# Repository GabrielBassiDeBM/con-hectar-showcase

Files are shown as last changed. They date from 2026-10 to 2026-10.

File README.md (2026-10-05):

<div align="center">

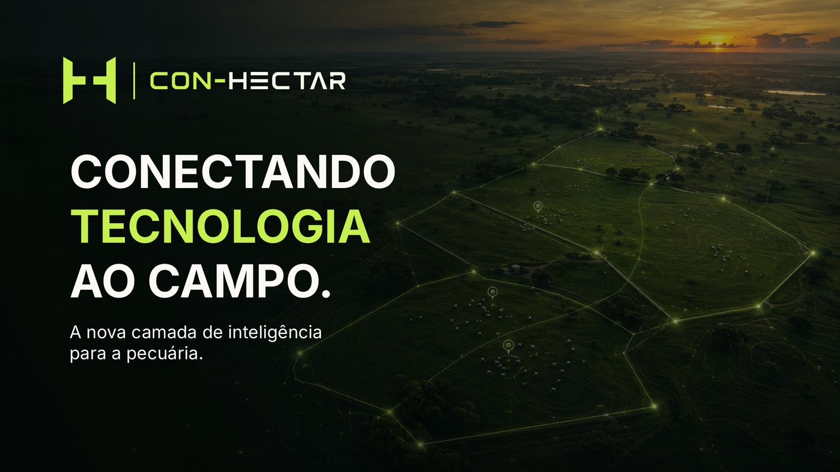
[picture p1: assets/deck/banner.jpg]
Con-Hectar — conectando tecnologia ao campo


<br/>
<br/>

<picture><source media="(prefers-color-scheme: dark)" srcset="assets/brand/logo-wordmark-tight-duotone.svg">Con-Hectar</picture>

### A nova camada de inteligência para a pecuária brasileira.

Coleiras GPS de baixo custo + rede LoRa própria + imagens de satélite Sentinel-2,<br/>
fundidas em um **sistema de decisão de pastejo**: quando tirar o lote, para onde mandar, e o que está errado agora.

<br/>

















[**Visão geral**](#-o-problema) ·
[**Como funciona**](#-como-funciona) ·
[**O que já foi construído**](#-o-que-já-foi-construído) ·
[**Hardware**](#-hardware) ·
[**Plataforma**](#-plataforma) ·
[**Inteligência**](#-a-inteligência) ·
[**Mercado**](#-mercado) ·
[**Roadmap**](#-desafios-e-próximos-passos)

</div>

---

> [!NOTE]
> **Este é um repositório de apresentação.** Ele documenta o que a Con-Hectar construiu — hardware, firmware, gateway, nuvem, painel web, app e motores de decisão — com fotos reais, arquitetura e números medidos em bancada. O código-fonte de produção é proprietário e fica em repositório privado; acesso para avaliação técnica pode ser concedido sob demanda.

<br/>

<p align="center">
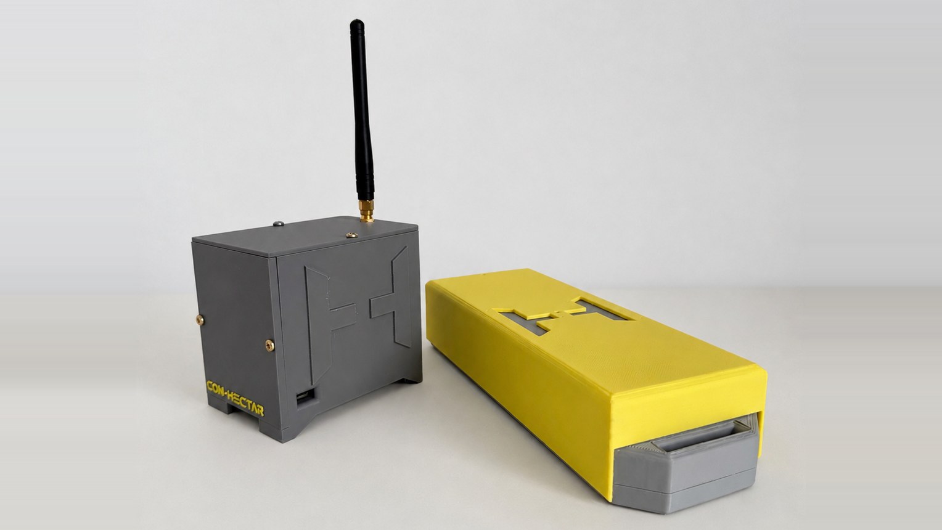
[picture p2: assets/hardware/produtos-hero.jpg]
Gateway (cinza) e coleira (amarela) da Con-Hectar
  
</p>
<p align="center"><sub><b>Hardware próprio.</b> O gateway (cinza) e a coleira (amarela) — eletrônica, firmware e cases projetados e impressos pela Con-Hectar.</sub></p>

<br/>

## ◆ O problema

<table>
<tr>
<td width="55%" valign="top">

A pecuária de corte brasileira é a maior do mundo em rebanho comercial — e uma das menos produtivas por hectare. A fazenda média produz **~5 @/ha/ano**; a fazenda bem manejada produz **12,9 @/ha/ano**. São **2,7×** de diferença na mesma terra, e **≈ R$ 441/ha/ano** de margem bruta deixada na porteira.

A maior parte desse gap não é genética nem insumo. É **manejo de pasto**: decidir *quando* tirar o lote de um piquete e *para onde* mandá-lo. Hoje isso é feito no "olhômetro", com uma ronda que, em fazenda extensiva, acontece a cada 3, 7 ou 15 dias.

Os produtos que já existem escolhem um lado: ou olham para o **animal** (rastreadores, brincos) ou olham para o **pasto** (satélite, NDVI). Nenhum funde os dois.

</td>
<td width="45%" valign="top">

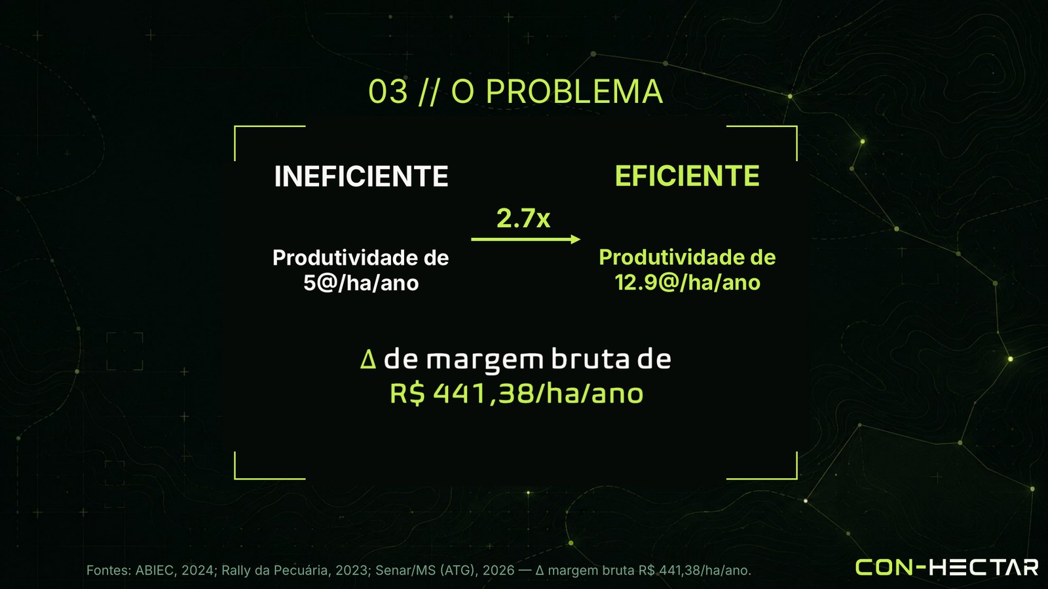
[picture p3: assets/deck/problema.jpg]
Ineficiente 5@/ha/ano vs eficiente 12,9@/ha/ano


<sub>Fontes: ABIEC, 2024; Rally da Pecuária, 2023; Senar/MS (ATG), 2026.</sub>

</td>
</tr>
</table>

### A tese

> **O rebanho avisa que o piquete acabou antes de o satélite conseguir enxergar isso.**
>
> Conforme a forragem se esgota, o bovino aumenta o tempo de pastejo e a distância percorrida de forma monotônica e mensurável. O satélite diz o que **tem** no piquete; o animal diz o que ele **acha** que tem. Quando os dois discordam, o animal ganha — porque ele está lá dentro. **Essa fusão é o produto.**

A Con-Hectar não vende rastreador. Vende um **sistema de suporte à decisão de pastejo cujo sensor primário é o próprio rebanho**, respondendo — sem que ninguém pergunte — às três perguntas que custam dinheiro na fazenda:

| | Pergunta | Hoje | Com a Con-Hectar |
|:-:|---|---|---|
| **1** | Quando tiro o lote deste piquete? | Olhômetro do capataz | Voto combinado **satélite × comportamento do rebanho** |
| **2** | Para onde mando? | Sequência fixa do croqui | Fila de rotação ranqueada pela forragem real e descanso aprendido |
| **3** | Tem algo errado com um animal ou com a infraestrutura? | Descoberto na próxima ronda | Alerta classificado, com evidência e ação sugerida |

<br/>

## ◆ Como funciona

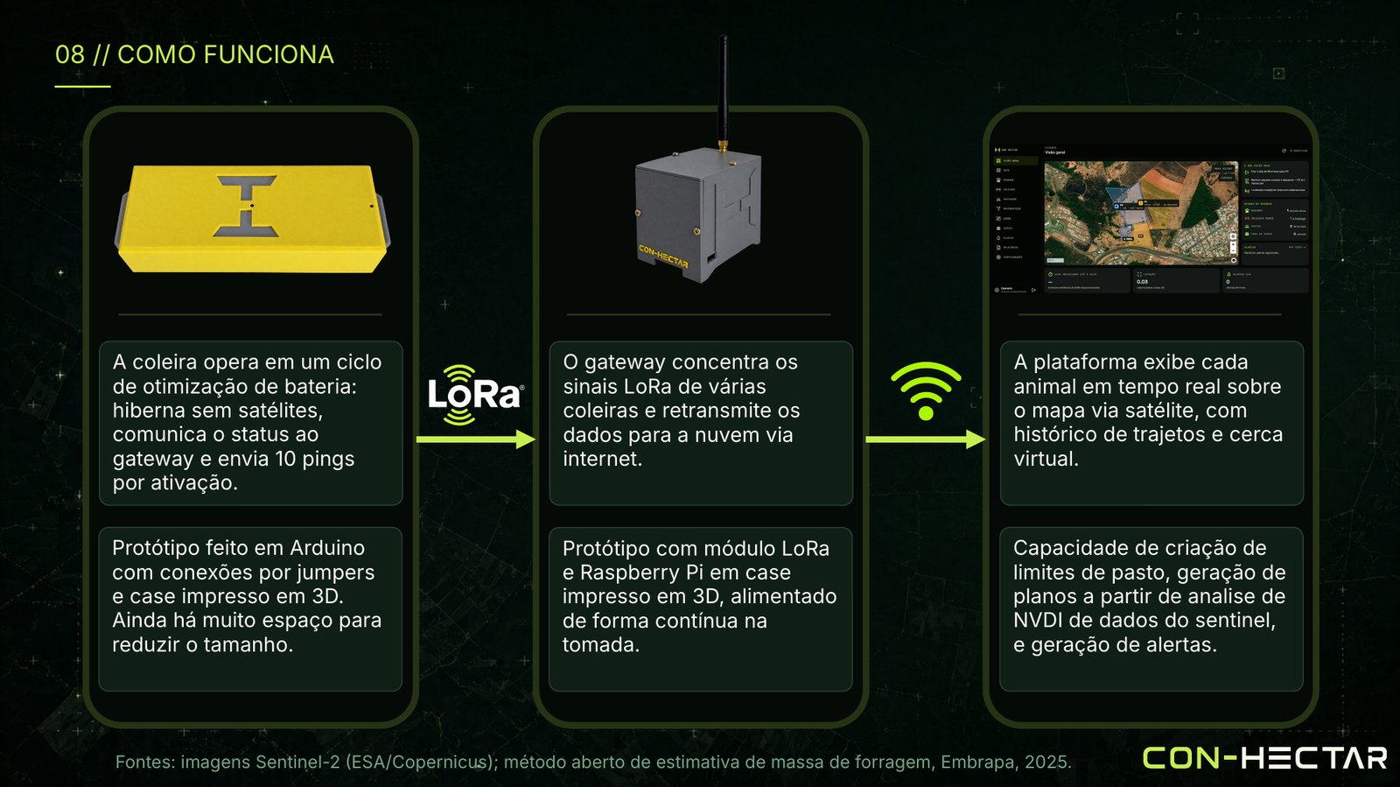
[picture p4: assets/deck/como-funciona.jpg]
Coleira → LoRa → Gateway → Nuvem → Plataforma


1. **Coleira** — acorda, obtém um fixo GPS, transmite por LoRa até receber confirmação do gateway e volta a dormir. Projetada para economizar bateria acima de tudo.
2. **Gateway** — concentra os sinais LoRa de várias coleiras, confirma o recebimento assim que o dado está **no próprio disco**, e encaminha para a nuvem sempre que houver internet. Continua operando quando a internet da fazenda cai.
3. **Nuvem** — cada fixo é imutável; métricas, rotação e alertas são derivados e recalculáveis. Imagens Sentinel-2 alimentam o NDVI de cada piquete automaticamente.
4. **Plataforma** — mapa em tempo real, cercas virtuais, plano de pastejo rotativo, saúde do rebanho e uma central de alertas que nunca confunde "animal parado" com "coleira sem sinal".

➜ Detalhes em [`docs/arquitetura.md`](docs/arquitetura.md)

<br/>

## ◆ O que já foi construído

Tudo abaixo existe, roda, e foi construído do zero — da solda ao pixel.

<table>
<tr>
<td width="50%" valign="top">

#### 🔧 Hardware & firmware
- [x] Coleira GPS + LoRa em Arduino, com case impresso em 3D
- [x] Firmware com ciclo de energia: GPS → transmite → aguarda ACK → dorme
- [x] Protocolo de rádio próprio com checksum, endereçamento e número de sequência
- [x] Anticolisão entre coleiras (jitter e backoff aleatórios por dispositivo)
- [x] Gerenciamento de energia do MCU e *sleep* do rádio por pinos de modo
- [x] Gateway em Raspberry Pi 5 com módulo LoRa, case 3D e serviço `systemd`
- [x] **Store-and-forward**: buffer local em SQLite que sobrevive a quedas de internet
- [x] Modelos 3D próprios da coleira e do gateway ([abrir no visualizador 3D](models/coleira.stl))

</td>
<td width="50%" valign="top">

#### ☁️ Nuvem & plataforma
- [x] Schema Postgres completo com Row Level Security
- [x] Stream de posições ao vivo via **Server-Sent Events**, autenticado
- [x] Painel web com **11 módulos** (mapa, rebanho, coleiras, cercas, pastagens, movimentação, saúde, alertas, relatórios…)
- [x] Desenho de cercas e piquetes direto no mapa de satélite
- [x] **Sincronização automática de NDVI** (Sentinel-2) por piquete
- [x] **Divisão automática de pastagens** em piquetes de área pastejável equivalente
- [x] **Motor de rotação**, **motor de anomalias** e **classificador de silêncio**
- [x] App de campo multiplataforma (iOS / Android / Web) em Expo
- [x] Landing page com visualizador 3D do hardware

</td>
</tr>
</table>

<br/>

## ◆ Hardware

Dois dispositivos, projetados do zero: a **coleira**, que vai no pescoço do animal, e o **gateway**, que fica na sede da fazenda.

<table>
<tr>
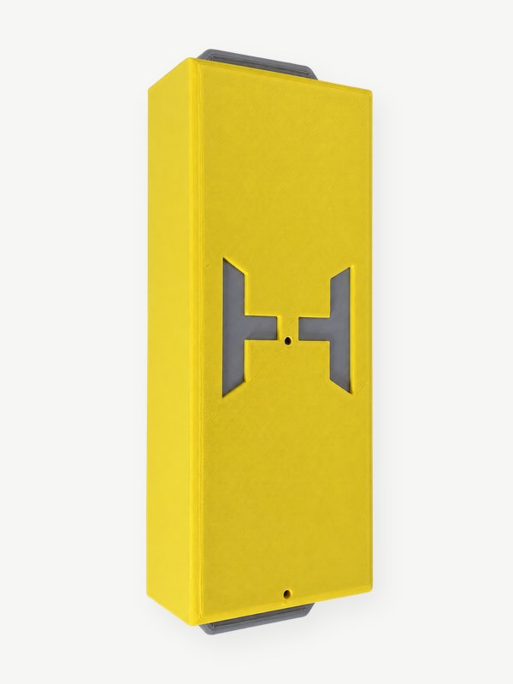
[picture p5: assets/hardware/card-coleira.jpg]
Coleira
<td align="center" width="25%"></td>
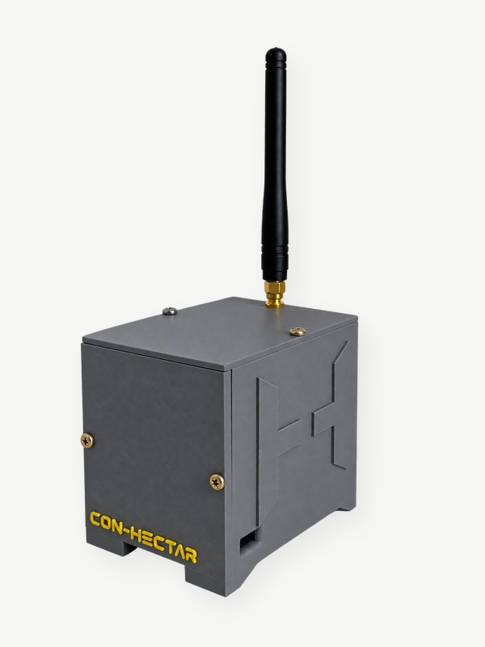
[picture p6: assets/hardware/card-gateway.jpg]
Gateway
<td align="center" width="25%"></td>
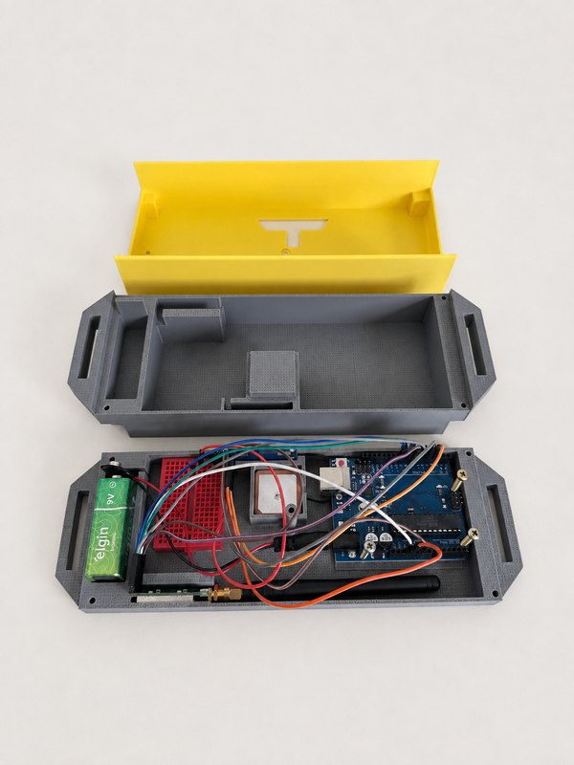
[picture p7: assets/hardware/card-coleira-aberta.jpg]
Coleira aberta mostrando a eletrônica
<td align="center" width="25%"></td>
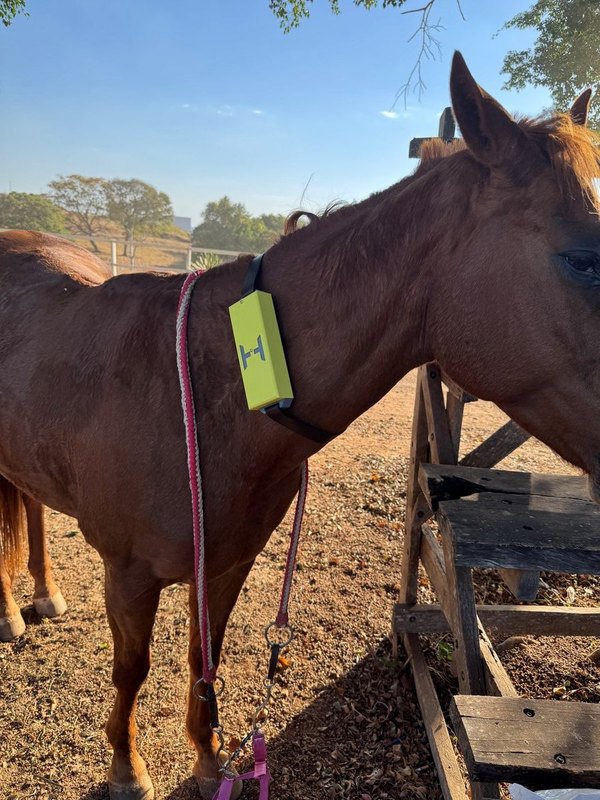
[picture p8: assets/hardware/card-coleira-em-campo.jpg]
Coleira instalada em um animal
<td align="center" width="25%"></td>
</tr>
<tr>
<td align="center" valign="top"><sub><b>Coleira</b><br/>GNSS + LoRa, a bateria</sub></td>
<td align="center" valign="top"><sub><b>Gateway</b><br/>Raspberry Pi 5 + LoRa, na sede</sub></td>
<td align="center" valign="top"><sub><b>Por dentro da coleira</b><br/>MCU, GNSS, rádio e bateria</sub></td>
<td align="center" valign="top"><sub><b>Teste em animal</b><br/>Fixação no pescoço</sub></td>
</tr>
</table>

#### Da folha de caderno ao campo

<table>
<tr>
<th width="25%">① Esquemático</th>
<th width="25%">② Coleira na bancada</th>
<th width="25%">③ Gateway na bancada</th>
<th width="25%">④ Case final</th>
</tr>
<tr>
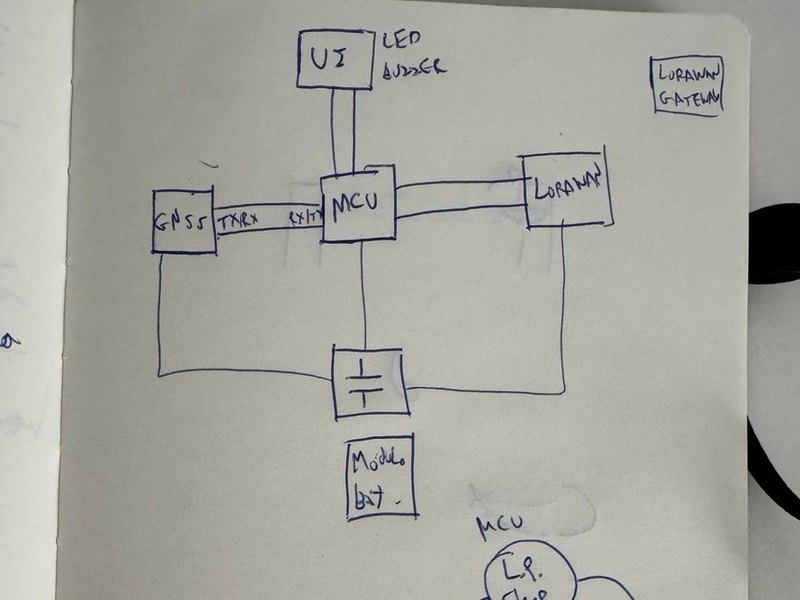
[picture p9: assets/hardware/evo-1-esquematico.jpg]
Esquemático à mão
<td></td>
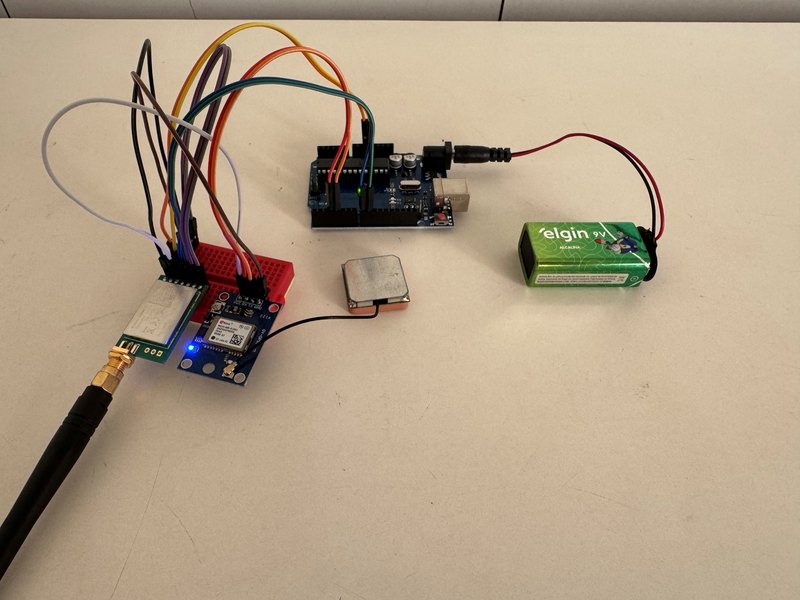
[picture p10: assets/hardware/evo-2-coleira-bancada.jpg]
Coleira em protoboard
<td></td>
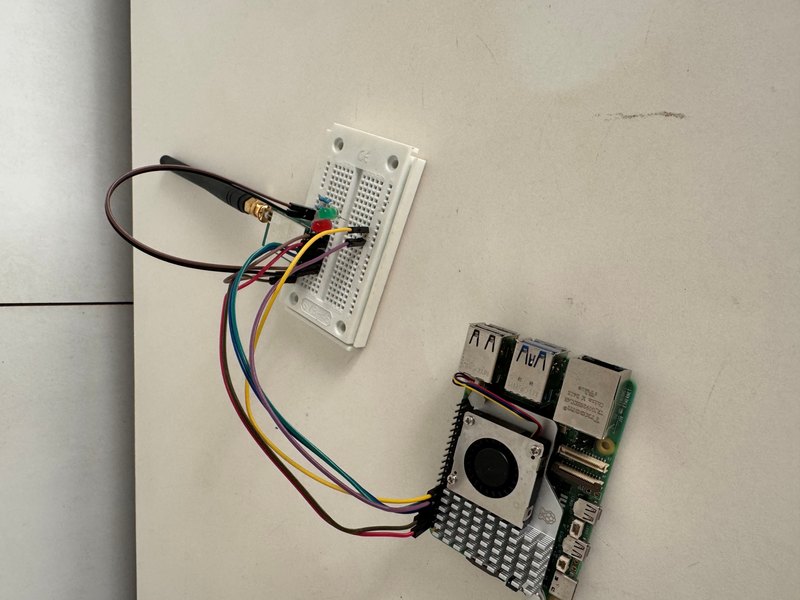
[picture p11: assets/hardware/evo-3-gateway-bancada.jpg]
Gateway em protoboard
<td></td>
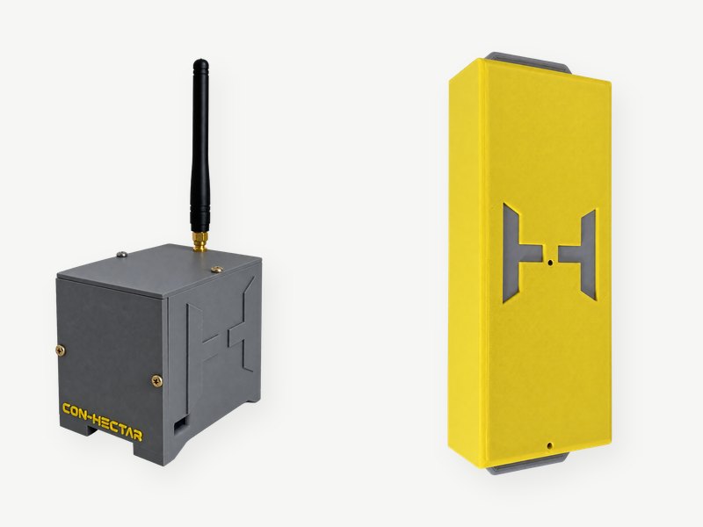
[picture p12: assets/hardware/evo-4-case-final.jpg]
Cases finais
<td></td>
</tr>
<tr>
<td align="center" valign="top"><sub>Arquitetura e ciclo de sono rascunhados à mão</sub></td>
<td align="center" valign="top"><sub>MCU + GNSS + LoRa em jumpers</sub></td>
<td align="center" valign="top"><sub>Raspberry Pi 5 + LoRa via UART</sub></td>
<td align="center" valign="top"><sub>Cases projetados e impressos em 3D</sub></td>
</tr>
</table>

#### Modelos 3D

Os cases foram modelados do zero — são os mesmos modelos do visualizador 3D da landing page. Clique em uma imagem para abrir o modelo no visualizador interativo do GitHub e **girar, aproximar e inspecionar**.

<table>
<tr>
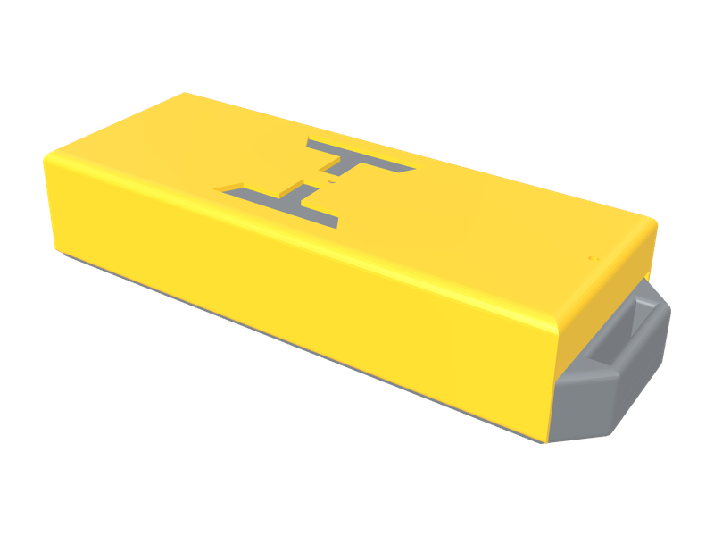
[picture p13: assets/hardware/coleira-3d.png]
Modelo 3D da coleira
<td align="center" width="50%"></td>
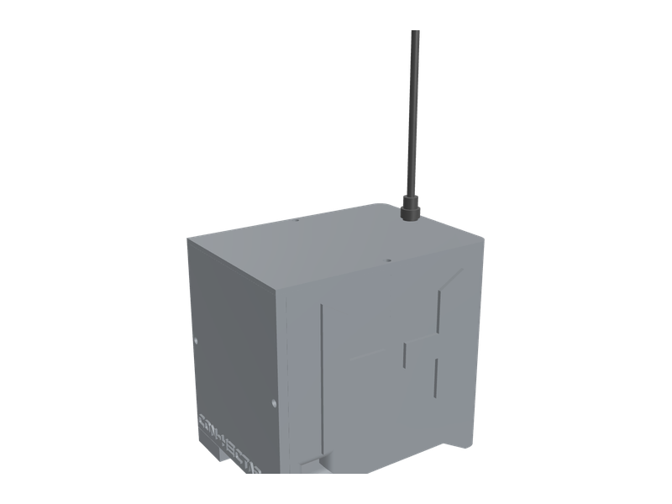
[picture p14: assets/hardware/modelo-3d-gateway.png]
Modelo 3D do gateway
<td align="center" width="50%"></td>
</tr>
<tr>
<td align="center"><a href="models/coleira.stl"><b>Coleira</b></a> · <code>models/coleira.stl</code></td>
<td align="center"><a href="models/gateway.stl"><b>Gateway</b></a> · <code>models/gateway.stl</code></td>
</tr>
</table>

#### Especificações

| Componente | Coleira | Gateway |
|---|---|---|
| **Processamento** | Microcontrolador AVR (protótipo) → MCU de baixo consumo (próxima rev.) | Raspberry Pi 5 · Debian 13 |
| **Posicionamento** | GNSS u-blox | — |
| **Rádio** | LoRa sub-GHz, faixa ISM ANATEL | LoRa sub-GHz, mesma faixa |
| **Software** | Firmware C++ com máquina de estados de energia | Serviço Python: ACK · armazenar · encaminhar · podar |
| **Persistência** | — | SQLite local (sobrevive a quedas de internet) |
| **Alimentação** | Bateria | Contínua (tomada) |
| **Case** | Impresso em 3D, projeto próprio | Impresso em 3D, projeto próprio |

➜ Detalhes em [`docs/hardware.md`](docs/hardware.md)

<br/>

## ◆ Plataforma

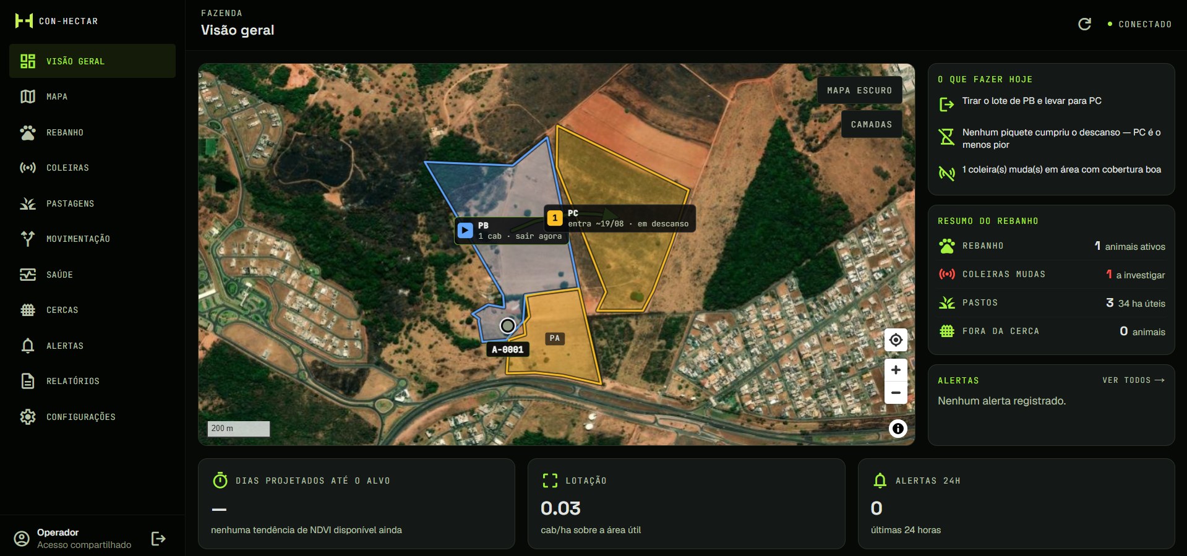
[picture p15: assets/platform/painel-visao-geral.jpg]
Painel Con-Hectar — visão geral


<sub>Painel em funcionamento: mapa de satélite com piquetes, lotes e coleiras ao vivo; à direita, "o que fazer hoje" e o resumo do rebanho.</sub>

<table>
<tr>
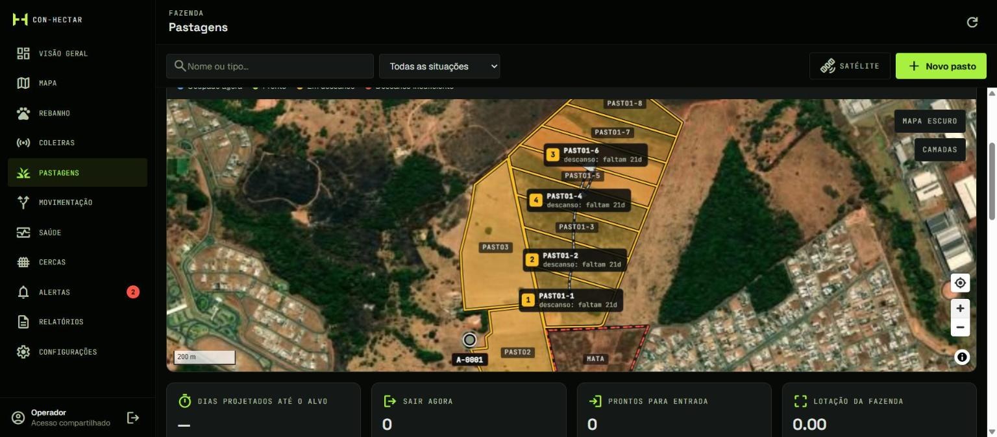
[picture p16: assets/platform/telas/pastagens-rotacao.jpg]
Pastagens — mapa da rotação
<td width="50%"></td>
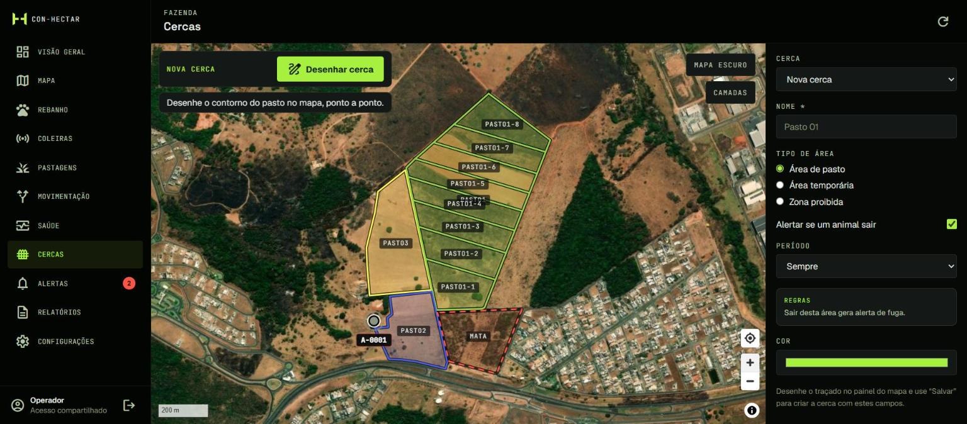
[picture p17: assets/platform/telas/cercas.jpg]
Cercas virtuais
<td width="50%"></td>
</tr>
<tr>
<td valign="top"><sub><b>Pastagens</b> — pastagem dividida automaticamente em 8 piquetes, com a fila de rotação numerada e o tempo de descanso restante de cada um.</sub></td>
<td valign="top"><sub><b>Cercas</b> — piquetes, área de mata como zona proibida e a coleira C0001 sobre imagem de satélite.</sub></td>
</tr>
<tr>
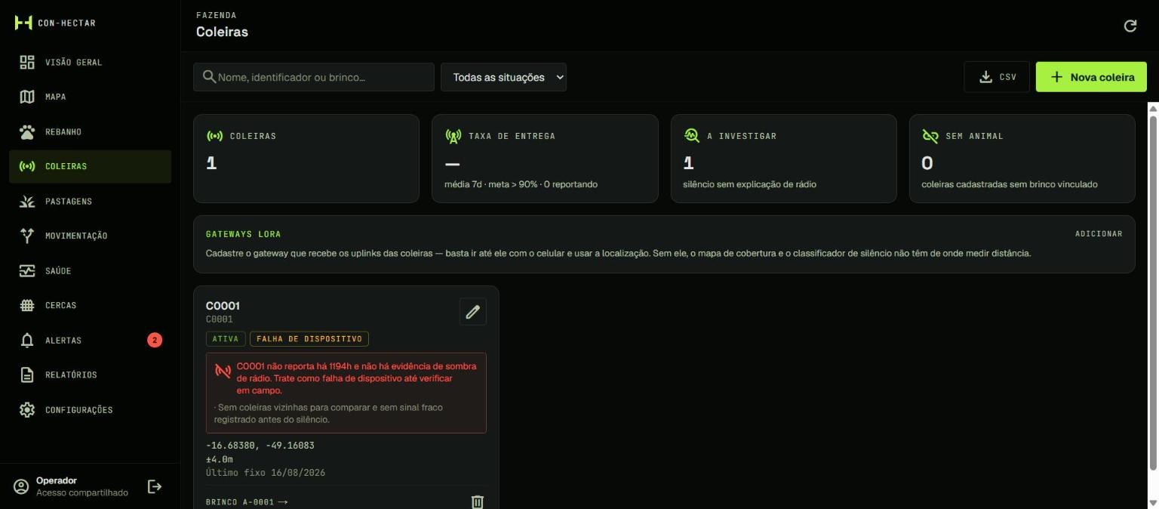
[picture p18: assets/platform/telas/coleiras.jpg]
Coleiras — diagnóstico de silêncio
<td width="50%"></td>
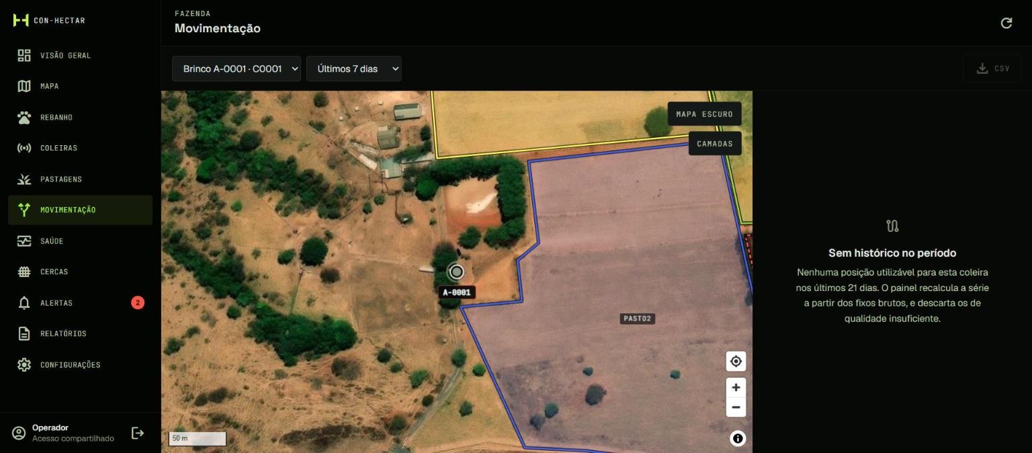
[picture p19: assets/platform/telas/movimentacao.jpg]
Movimentação
<td width="50%"></td>
</tr>
<tr>
<td valign="top"><sub><b>Coleiras</b> — o classificador de silêncio em ação: sem sombra de rádio que explique, a coleira é marcada como falha de dispositivo.</sub></td>
<td valign="top"><sub><b>Movimentação</b> — trajeto por animal e período; dias sem fixos de qualidade são recusados em vez de inventados.</sub></td>
</tr>
</table>

| Módulo | O que resolve |
|---|---|
| **Visão geral** | O que fazer hoje — recomendações priorizadas, não um mural de gráficos |
| **Mapa** | Cada animal em tempo real sobre imagem de satélite, com trajetos, gateways e pontos de recurso (cocho, água) |
| **Rebanho** | Cadastro de animais e lotes, vínculo animal ↔ coleira com histórico temporal |
| **Coleiras** | Estado de cada dispositivo, qualidade de rádio e diagnóstico de silêncio |
| **Cercas** | Cercas virtuais com regras de entrada/saída por período, detecção de fuga com histerese |
| **Pastagens** | Piquetes, NDVI, estado (ocupado · pronto · descansando), fila de rotação e divisão automática |
| **Movimentação** | Distância, área de uso e orçamento de atividade por animal e por lote |
| **Saúde** | Eventos sanitários e anomalias comportamentais com evidência |
| **Alertas** | Central de alertas com severidade, explicação e ação sugerida |
| **Relatórios** | Indicadores históricos para decisão e prestação de contas |
| **Configurações** | Fazenda, intervalos de amostragem, limiares |

➜ Detalhes em [`docs/plataforma.md`](docs/plataforma.md)

<br/>

## ◆ A inteligência

A plataforma é organizada em **cinco camadas**, cada uma alimentando a seguinte. Todas são derivadas **apenas de posição, tempo e satélite** — sem prometer o que o hardware não mede.

```mermaid
flowchart LR
  L0["<b>0 · Dados</b><br/>fixos imutáveis"]
  L1["<b>1 · Comportamento</b><br/>~20 métricas<br/>por animal-dia"]
  L2["<b>2 · Piquete</b><br/>ciclo de ocupação"]
  L3["<b>3 · Satélite</b><br/>NDVI Sentinel-2"]
  L4["<b>4 · Rotação</b><br/>sair? para onde?"]
  L5["<b>5 · Alertas</b><br/>anomalias · silêncio"]
  L0 --> L1 --> L2 --> L4
  L3 --> L4
  L1 --> L5
  L4 --> L5
```

| Motor | O que faz | Por que é diferente |
|---|---|---|
| **Métricas comportamentais** | Distância filtrada, sinuosidade, área de uso, raio de giro, tempo em pastejo × deslocamento × repouso | Filtra a "caminhada fantasma" do erro de GPS e se recusa a comparar dias com intervalos de amostragem diferentes |
| **Rotação** | Decide quando sair do piquete por **voto de duas fontes** — satélite e comportamento — e ranqueia o próximo | Quando as fontes discordam, a interface **mostra a discordância** em vez de esconder |
| **Satélite (NDVI)** | Sincroniza Sentinel-2 por piquete e aprende os limiares de entrada/saída **do próprio histórico do piquete** | Zero calibração manual: nenhum operador escolhe espécie ou digita altura de capim |
| **Anomalias** | Falha de aguada, animal caído, doença, isolamento, coesão do rebanho, cio | Linha de base robusta (mediana/MAD), normalizada contra o próprio lote no mesmo dia, com persistência — e dez animais com a mesma anomalia viram **um** alerta de infraestrutura |
| **Silêncio** | Classifica por que uma coleira parou de falar: sombra de rádio, falha de dispositivo ou silêncio sem explicação | Um falso "animal morto" queima mais confiança do que dez acertos constroem |
| **Divisão de pastagens** | Corta uma pastagem em N piquetes de área pastejável equivalente, como um cerqueiro faria | Balanceada por NDVI; sugere N a partir de dias de descanso e ocupação |

➜ Detalhes em [`docs/inteligencia.md`](docs/inteligencia.md)

<br/>

## ◆ Medido, não estimado

Uma regra da casa: **o que foi medido é marcado como medido; o que foi calculado é marcado como calculado.**

| Verificação | Resultado | Tipo |
|---|:-:|---|
| Link GPS (sentenças NMEA com checksum válido) | **120 / 0** | ✅ medido |
| Frames de rádio coleira → gateway | **6 / 0 perdidos** | ✅ medido |
| Latência de ingestão (fixo armazenado → nuvem) | **7 s** | ✅ medido |
| Stream ao vivo sem / com sessão | **401 / 200** | ✅ medido |
| Ganho do sono do MCU no consumo médio | ≈ 2 % | ⚠️ calculado — revelou que o gargalo é o GNSS e a placa, não o MCU |

➜ Diário completo, incluindo as falhas encontradas, em [`docs/engenharia.md`](docs/engenharia.md)

<br/>

## ◆ Mercado

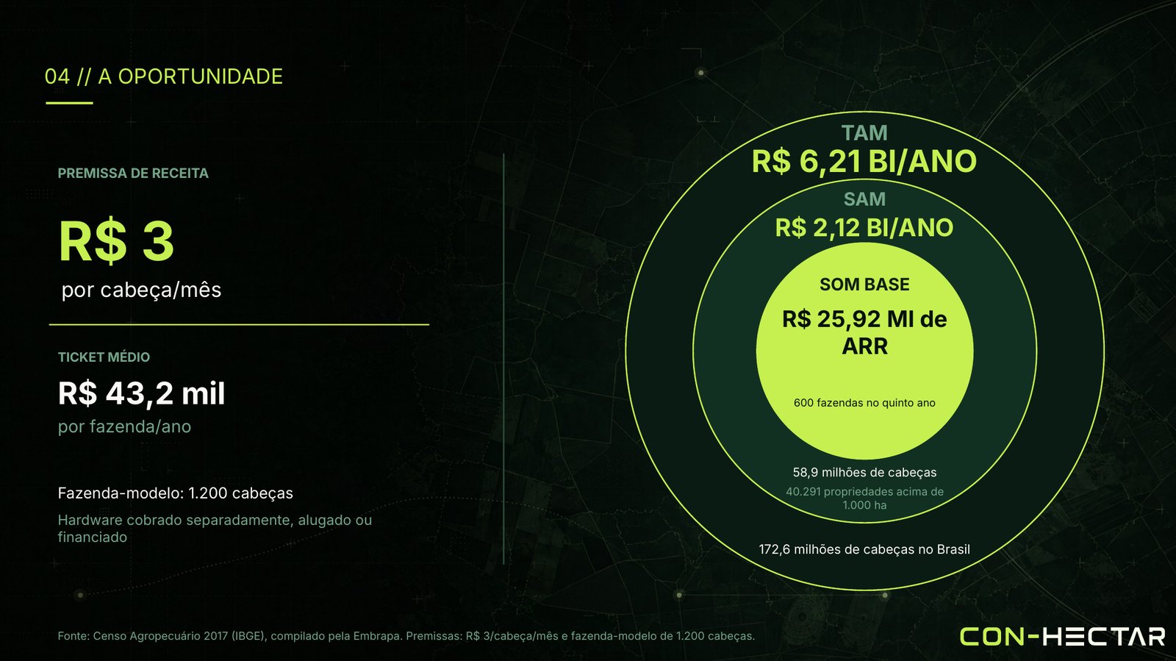
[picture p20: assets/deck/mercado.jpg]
TAM, SAM e SOM


<p align="center">
🐂 <b>238 mi</b> cabeças de gado &nbsp;·&nbsp; 🌱 <b>167 mi ha</b> de pastagem &nbsp;·&nbsp; 💰 <b>R$ 1,1 tri</b> movimentados por ano
</p>

**Modelo:** assinatura de **R$ 3 por cabeça/mês** (ticket médio de R$ 43,2 mil/fazenda/ano numa fazenda-modelo de 1.200 cabeças). Hardware cobrado à parte — venda, aluguel ou financiamento. Cobrar por cabeça, e não por coleira, só se justifica porque o produto entrega **decisão**, não posição.

➜ Detalhes em [`docs/negocio.md`](docs/negocio.md)

<br/>

## ◆ Desafios e próximos passos

<table>
<tr>
<td width="50%" valign="top">

#### Desafios honestos
- Conexão do gateway à internet instável no último teste de campo, feito sem Starlink
- Jumpers e módulos de prateleira elevaram custo e tamanho da coleira
- Imagens de satélite escassas em períodos de seca geraram erros nos piquetes
- O sono do MCU rende pouco: o consumo está no GNSS e na placa de desenvolvimento

</td>
<td width="50%" valign="top">

#### Próximos passos
- [ ] Estabilizar o link do gateway em campo
- [ ] **Cyberdeck**: gateway com sistema operacional e tela próprios, para monitorar o rebanho na fazenda sem depender de rede
- [ ] Melhorar a geração automática de piquetes
- [ ] Coleira em **PCB própria** com MCU de baixo consumo
- [ ] Modo *power-save* do GNSS e buffer de fixos na coleira
- [ ] Piloto com **+1 coleira ativa** e depois um lote inteiro

</td>
</tr>
</table>

➜ Roadmap completo em [`docs/negocio.md#roadmap`](docs/negocio.md#roadmap)

<br/>

## ◆ Linha do tempo

| Fase | Marco | Entregas |
|:-:|---|---|
| **01** | Entender o problema | Pesquisa e conversas com pecuaristas · esquemático da eletrônica · consolidação da tese |
| **02** | Provar a cadeia | Eletrônica em bancada · fazenda-piloto definida · documento de requisitos de produto · planejamento do software |
| **03** · *atual* | Construir o produto | **15/08** coleira C0001 → gateway → nuvem → mapa ao vivo, ponta a ponta · **19/08** motor de rotação, sync NDVI Sentinel-2, divisão automática de piquetes e motor de alertas · cases 3D, modelos 3D e teste de fixação em animal |

<br/>

## ◆ Documentação

| Documento | Conteúdo |
|---|---|
| [`docs/arquitetura.md`](docs/arquitetura.md) | Cadeia ponta a ponta, protocolo de rádio, modelo de dados, decisões de projeto, segurança |
| [`docs/hardware.md`](docs/hardware.md) | Coleira, gateway, ciclo de energia, análise de consumo, evolução do protótipo |
| [`docs/plataforma.md`](docs/plataforma.md) | Painel web, app de campo, sistema de design e princípios de produto |
| [`docs/inteligencia.md`](docs/inteligencia.md) | As cinco camadas: métricas, satélite, rotação, anomalias e silêncio |
| [`docs/engenharia.md`](docs/engenharia.md) | O que foi medido, falhas encontradas e como foram resolvidas, itens em aberto |
| [`docs/negocio.md`](docs/negocio.md) | Problema, mercado, concorrência, modelo de receita e roadmap |

<br/>

---

<div align="center">



**Con-Hectar** · Goiânia, GO

Fundador: **Gabriel Bassi** — [gabrielbassidebm@gmail.com](mailto:gabrielbassidebm@gmail.com)

<sub>© 2026 Con-Hectar. Todos os direitos reservados. Fotos, renders, marcas e documentação deste repositório não podem ser reproduzidos sem autorização.</sub>

</div>

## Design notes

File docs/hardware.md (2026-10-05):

<picture><source media="(prefers-color-scheme: dark)" srcset="../assets/brand/logo-wordmark-tight-duotone.svg">Con-Hectar</picture>

# Hardware

[← Voltar ao README](../README.md)

Gateway (cinza) e coleira (amarela)

Dois dispositivos, ambos projetados, montados, programados e encapsulados pela Con-Hectar: a **coleira** (amarela), que vai no animal, e o **gateway** (cinza), que fica na sede da fazenda.

---

## Coleira

<table>
<tr>
<td width="30%" align="center" valign="top">Coleira</td>
<td valign="top">

**Função:** acordar, obter um fixo GNSS, entregá-lo ao gateway com confirmação e voltar a dormir — gastando o mínimo de energia possível.

**Protótipo atual**
- Microcontrolador AVR em placa de desenvolvimento
- Receptor GNSS u-blox
- Transceptor LoRa sub-GHz em modo transparente
- Bateria e chave de alimentação
- Case impresso em 3D, com encaixe para correia

**Firmware** em C++, organizado como uma máquina de estados de energia. A coleira opera em um ciclo de otimização de bateria: hiberna sem satélites, comunica o status ao gateway e envia uma rajada de pings por ativação.

</td>
</tr>
</table>

### O ciclo de trabalho

```
acorda
 ├─ escuta o GNSS até obter um fixo NOVO (ou estourar o tempo)
 ├─ monta o frame: $P (fixo) ou $S (sem fixo)
 ├─ troca a escuta para o rádio
 ├─ atraso aleatório
 ├─ até N tentativas:  transmite → aguarda ACK → backoff aleatório
 ├─ seq++
 └─ dorme: rádio em modo sleep, MCU em power-down
```

Três armadilhas resolvidas de forma deliberada no firmware:

- **O relógio do MCU congela no power-down**, então a "idade" do fixo não distingue um fixo novo do anterior. A coleira espera o contador de fixos do GNSS avançar.
- **As portas seriais em software ficam em interrupções de mudança de pino.** São desligadas explicitamente antes de dormir — caso contrário, o próximo caractere do GNSS acordaria o MCU na hora e o sono nunca aconteceria.
- **A libc do AVR não formata ponto flutuante.** Coordenadas passam por conversão dedicada; sem isso, latitude e longitude seriam transmitidas vazias.

### Energia — a análise que mudou o roadmap

Implementamos o sono profundo do MCU, o desligamento de periféricos internos e o sono do rádio via pinos de modo. Depois, fizemos a conta honesta:

| Carga | Antes | Depois | Alcançável por firmware? |
|---|---:|---:|---|
| Receptor GNSS | alta | alta | Só com comandos UBX — exige um fio a mais |
| Rádio LoRa | média | ≈ 0 | **Sim** — agora dorme |
| Placa de desenvolvimento (USB, LED, regulador) | média | média | Não — é da placa |
| Microcontrolador | baixa | piso | **Sim** — já no mínimo |
| **Média do ciclo** | | | **≈ 2 % melhor** *(calculado, não medido)* |

**Conclusão:** o MCU é a menor carga do sistema por três ordens de grandeza. O ganho real está em (1) colocar o GNSS em modo de economia, (2) mudar a razão acordado/dormindo e (3) **sair da placa de desenvolvimento para uma PCB própria com MCU de baixo consumo** — exatamente o que está no roadmap. Essa análise evitou que dimensionássemos uma bateria com base numa otimização que não existia.

---

## Gateway

<table>
<tr>
<td width="30%" align="center" valign="top">Gateway</td>
<td valign="top">

**Função:** concentrar os sinais LoRa de várias coleiras e retransmitir os dados para a nuvem via internet.

- Raspberry Pi 5, Debian 13
- Módulo LoRa ligado por UART
- Antena externa
- Case impresso em 3D
- Alimentação contínua (tomada)

**Software:** serviço Python gerenciado por `systemd`, que reinicia sozinho e sobe no boot. Quatro responsabilidades:

1. **Confirmar** cada frame válido com o ACK endereçado
2. **Armazenar** em SQLite local, antes de qualquer outra coisa
3. **Encaminhar** para a nuvem quando houver internet
4. **Podar** o buffer com um teto de retenção

Inclui ainda um script de preparação que libera a UART em um Pi recém-instalado e um monitor passivo para trabalho de bancada.

</td>
</tr>
</table>

---

## Evolução do protótipo

<table>
<tr>
<th width="25%">Fase 01 · Esquemático</th>
<th width="25%">Fase 02 · Coleira</th>
<th width="25%">Fase 02 · Gateway</th>
<th width="25%">Fase 03 · Case</th>
</tr>
<tr>
<td>Esquemático</td>
<td>Coleira em bancada</td>
<td>Gateway em bancada</td>
<td>Cases finais</td>
</tr>
<tr>
<td valign="top"><sub>Blocos, barramentos e ciclo de sono desenhados à mão — já apontando para um MCU de baixo consumo e chave eletrônica na alimentação</sub></td>
<td valign="top"><sub>MCU + GNSS + LoRa + bateria em jumpers</sub></td>
<td valign="top"><sub>Raspberry Pi 5 + LoRa em protoboard</sub></td>
<td valign="top"><sub>Coleira e gateway nos cases impressos em 3D</sub></td>
</tr>
</table>

### Em animal

<table>
<tr>
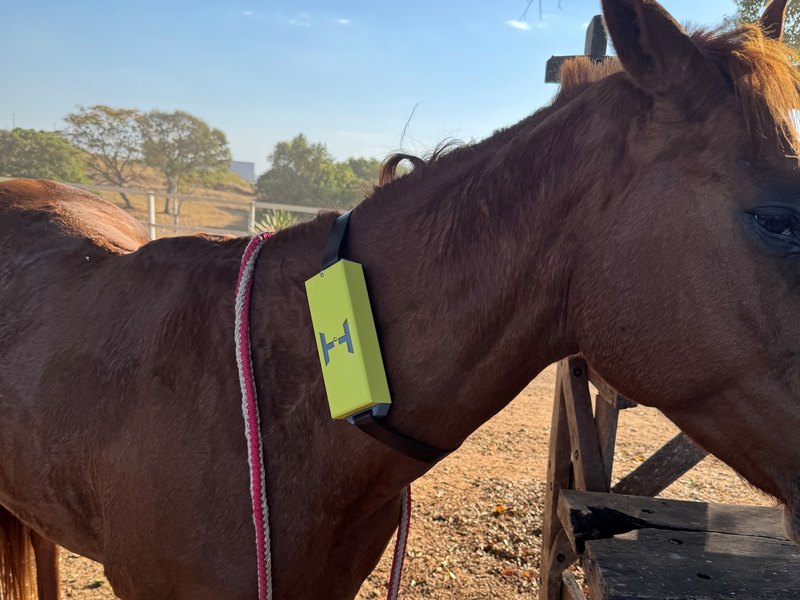
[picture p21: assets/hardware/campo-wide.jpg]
Coleira em animal
<td width="50%" align="center"></td>
<td valign="top">

Teste de fixação da coleira, já no case final, no pescoço de um animal.

O teste valida o encaixe da correia e o posicionamento do case. Os próximos passos de campo estão no fim desta página: PCB própria e uma segunda coleira ativa.

</td>
</tr>
</table>

### Modelos 3D

Os cases foram modelados do zero. Clique para abrir no visualizador 3D interativo do GitHub — os mesmos modelos aparecem na landing page, renderizados com Three.js.

<table>
<tr>
<td align="center" width="50%"><a href="../models/coleira.stl">Modelo 3D da coleira</a></td>
<td align="center" width="50%"><a href="../models/gateway.stl">Modelo 3D do gateway</a></td>
</tr>
<tr>
<td align="center"><a href="../models/coleira.stl"><b>Coleira</b></a> · <code>models/coleira.stl</code></td>
<td align="center"><a href="../models/gateway.stl"><b>Gateway</b></a> · <code>models/gateway.stl</code></td>
</tr>
</table>

---

## Próxima revisão

| Item | Por quê |
|---|---|
| **PCB própria** | Elimina jumpers e a placa de desenvolvimento: menor custo, menor tamanho, menor consumo de base |
| **MCU de baixo consumo** | Sono real em microamperes |
| **GNSS em modo power-save** | Atua sobre 100 % do tempo, não sobre a fração em que a coleira dorme |
| **Buffer de fixos na coleira** | Hoje, se a coleira não alcança o gateway, o fixo do ciclo é descartado. Com buffer, ela descarrega o histórico ao voltar à cobertura ("modo mochila") |
| **Medição de bateria** | Só será mostrada no painel quando for medida de verdade |
| **Segunda coleira ativa** | Validar anticolisão e endereçamento em campo |
| **Gateway como cyberdeck** | O link de internet ficou instável no último teste (sem Starlink). Com sistema operacional e tela próprios, o gateway passa a mostrar o rebanho direto na sede, sem depender de rede — a nuvem vira sincronização, não requisito |

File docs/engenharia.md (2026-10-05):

<picture><source media="(prefers-color-scheme: dark)" srcset="../assets/brand/logo-wordmark-tight-duotone.svg">Con-Hectar</picture>

# Diário de engenharia

[← Voltar ao README](../README.md)

Extraído do relatório de sistema da coleira **C0001**: o que foi medido no sistema rodando, as falhas encontradas — cada uma se apresentando como algo diferente do que era — e o que continua em aberto.

---

## O que foi medido

Do sistema em funcionamento, não de raciocínio sobre ele.

| Verificação | Resultado | Por que essa é a verificação certa |
|---|:-:|---|
| Link GPS | **120 / 0** sentenças com checksum válido / inválido | A contagem de caracteres sobe mesmo lendo ruído no baud errado; só checksums válidos provam o link |
| Frames de rádio | **6 / 0 perdidos** | O gateway decodificou byte a byte o que a coleira imprimiu, confirmado por contadores nas duas pontas |
| Latência de ingestão | **7 s** | Fixo gravado às 03:30:48, enviado às 03:30:55 |
| Gatilho de retenção | **6 → 3** | Verificado com um teto reduzido num dispositivo descartável; dados reais intocados, teto restaurado |
| Autenticação do stream | **401 / 200** | Recusado sem cookie de sessão, servido com ele |

```
03:30:48  C0001 seq=26 -16.71…,-49.26… @ 03:30:47  (stored)
03:30:48    ack -> $A,C0001,26*07
03:30:55  uploaded 1
```

> ⚠️ **Consumo de energia: calculado, não medido.** Valores típicos de datasheet; nenhum multímetro esteve no sistema ainda. Ver [`hardware.md`](hardware.md#energia--a-análise-que-mudou-o-roadmap).

---

## Falhas encontradas

| Sintoma | O que realmente era | Correção |
|---|---|---|
| **O mapa abria na cidade errada** | Sem cercas nem centro da fazenda configurados, o mapa caía num padrão nacional enquanto a única coleira estava a ~200 km. Ela estava sendo desenhada o tempo todo — fora da tela. | Enquadramento automático nas coleiras ativas |
| **Frames corrompidos que não eram problema de rádio** | Caracteres faltando, mas os sobreviventes *em ordem* — dois processos lendo a mesma UART e roubando bytes um do outro. | Um único dono da porta serial |
| **Um comando funcionando que parecia morto** | Python bufferiza stdout num pipe; um monitor rodando via SSH não imprimia nada por minutos. Esse silêncio deixou o processo duplicado acima vivo. | Saída sem buffer |
| **Todo ciclo transmitindo duas vezes** | A tentativa 1 sempre expirava e a 2 sempre era confirmada. Pacote perdido é aleatório; "a primeira sempre falha" é uma resposta chegando depois da janela. Um teste A/B descartou o sono do rádio como causa. | Janela de ACK dobrada |
| **Um sentinela fingindo ser dado** | HDOP 99,99 ("sem precisão") chegava ao banco como precisão de ~500 m — um círculo que o mapa desenharia feliz. | Sentinelas filtrados na origem |
| **Um feed ao vivo sem autenticação** | O stream de posições ficava fora do código de acesso que protegia o painel acima dele. | Stream exige sessão |
| **Uma função interna exposta publicamente** | A API REST publica tudo no schema público; a função de retenção era chamável de fora. | Movida para fora do schema exposto |

---

## Decisões de produto tiradas da engenharia

- **O painel deixou de mostrar bateria.** Não há divisor nem leitura de ADC na coleira, então qualquer número seria inventado. Removemos toda superfície de bateria em vez de exibir um dado que teríamos de adivinhar.
- **O ACK não espera a nuvem** (ver [`arquitetura.md`](arquitetura.md#3-a-decisão-mais-importante-o-ack-não-espera-a-nuvem)).
- **A análise de energia redirecionou o roadmap** do firmware para a PCB.

---

## Em aberto

| Item | Tipo | Situação |
|---|---|---|
| Proteção de nível lógico entre MCU e rádio | Hardware | Mitigado em firmware em parte dos pinos; divisores resistivos pendentes |
| Coleira não guarda fixos quando não alcança o gateway | Perda de dados | Buffer em memória não volátil planejado ("modo mochila") |
| Conectividade do gateway | Implantação | Instável no último teste de campo, feito sem Starlink. Caminhos: um link de internet estável na sede, ou um **cyberdeck** — o gateway com sistema operacional e tela próprios, exibindo o rebanho localmente sem precisar de rede |
| Alertas de cerca derivados no navegador | Arquitetura | Funciona com o painel aberto; migrar a derivação para o gateway, que já vê todo fixo |
| Leitura de bateria | Funcionalidade | Depende da nova PCB |
| Validação da integração Sentinel-2 com conta de produção | Integração | Pendente de credenciais definitivas |

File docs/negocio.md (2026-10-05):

<picture><source media="(prefers-color-scheme: dark)" srcset="../assets/brand/logo-wordmark-tight-duotone.svg">Con-Hectar</picture>

# Negócio

[← Voltar ao README](../README.md)

> **Nossa direção:** a melhor versão do campo na palma da mão de quem mais precisa.

---

## O problema

Produtividade: 5 vs 12,9 @/ha/ano

| | Produtividade | |
|---|:-:|---|
| Fazenda ineficiente | **5 @/ha/ano** | |
| Fazenda eficiente | **12,9 @/ha/ano** | **2,7×** |
| Diferença de margem bruta | **R$ 441,38/ha/ano** | |

<sub>Fontes: ABIEC, 2024; Rally da Pecuária, 2023; Senar/MS (ATG), 2026.</sub>

O gap é, em grande parte, de **manejo de pastagem** — decidido hoje no olho, com rondas espaçadas e sem dado.

---

## O mercado

| Indicador | Valor | Fonte |
|---|:-:|---|
| Rebanho bovino | **238 mi** cabeças | IBGE, PPM 2024 |
| Movimentado pela cadeia | **R$ 1,1 tri/ano** | ABIEC, Beef Report 2026 |
| Área de pastagem | **167 mi ha** | ABIEC, Beef Report 2026 |

### Onde está o gado

| Faixa de área | Estabelecimentos | Cabeças | Participação no rebanho |
|---|:-:|:-:|:-:|
| Menos de 100 ha | 2.158.947 (84,75 %) | 50,1 mi | 29,03 % |
| De 100 a 1.000 ha | 348.101 (13,67 %) | 63,6 mi | 36,86 % |
| **Acima de 1.000 ha** | **40.291 (1,58 %)** | **58,9 mi** | **34,11 %** |

<sub>Fonte: Censo Agropecuário 2017 (IBGE), compilado no Anuário CiCarne 2025-2026 (Embrapa).</sub>

**1,58 % das propriedades detêm mais de um terço do rebanho.** É por aí que se começa.

### TAM · SAM · SOM

TAM SAM SOM

| | Valor | Base |
|---|:-:|---|
| **TAM** | R$ 6,21 bi/ano | 172,6 mi cabeças no Brasil |
| **SAM** | R$ 2,12 bi/ano | 58,9 mi cabeças em 40.291 propriedades acima de 1.000 ha |
| **SOM** | R$ 25,92 mi de ARR | 600 fazendas no quinto ano |

---

## Modelo de receita

| | |
|---|---|
| **Assinatura** | R$ 3 por cabeça/mês |
| **Ticket médio** | R$ 43,2 mil por fazenda/ano (fazenda-modelo de 1.200 cabeças) |
| **Hardware** | Cobrado separadamente — venda, aluguel ou financiamento |

Cobrar **por cabeça**, e não por coleira, é uma escolha deliberada: o valor entregue é decisão sobre o rebanho e a pastagem — e a funcionalidade que justifica esse modelo é a projeção de quando o pasto vai faltar.

---

## Concorrência

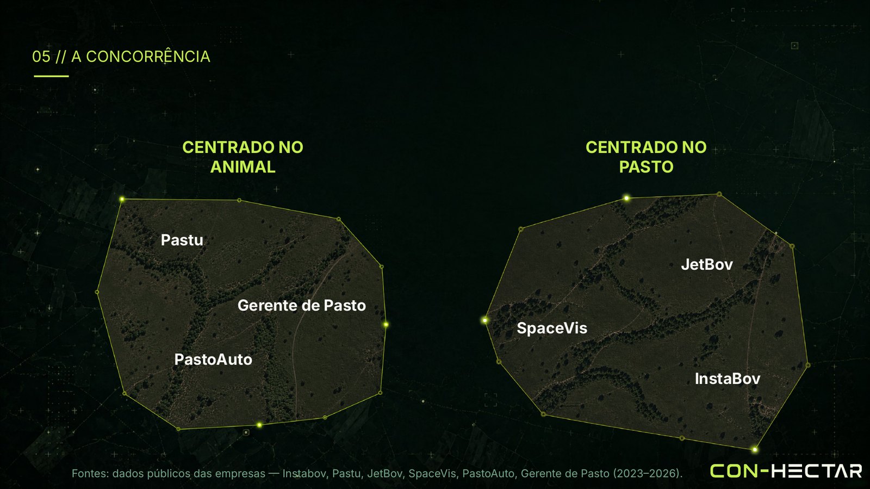
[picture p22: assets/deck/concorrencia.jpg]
Mapa da concorrência


| Centrados no animal | Centrados no pasto |
|---|---|
| JetBov · InstaBov · Gerente de Pasto | SpaceVis · PastoAuto · Pastu |

O mercado se divide entre quem olha para o **boi** e quem olha para o **capim**. A Con-Hectar se posiciona na interseção:

> **Buscamos capitalizar no que importa para o gado, sem deixar de olhar para ele.**

O diferencial não é a coleira — que tende a virar commodity — nem o dashboard — que é copiável. É a **fusão satélite × comportamento** e o ativo que ela gera: um rebanho de 1.000 cabeças acompanhado por uma safra produz na ordem de **300 mil animal-dias** rotulados com forragem observada por satélite. Esse corpus é a barreira de entrada real.

<sub>Fontes: dados públicos das empresas (2023–2026).</sub>

---

## Roadmap

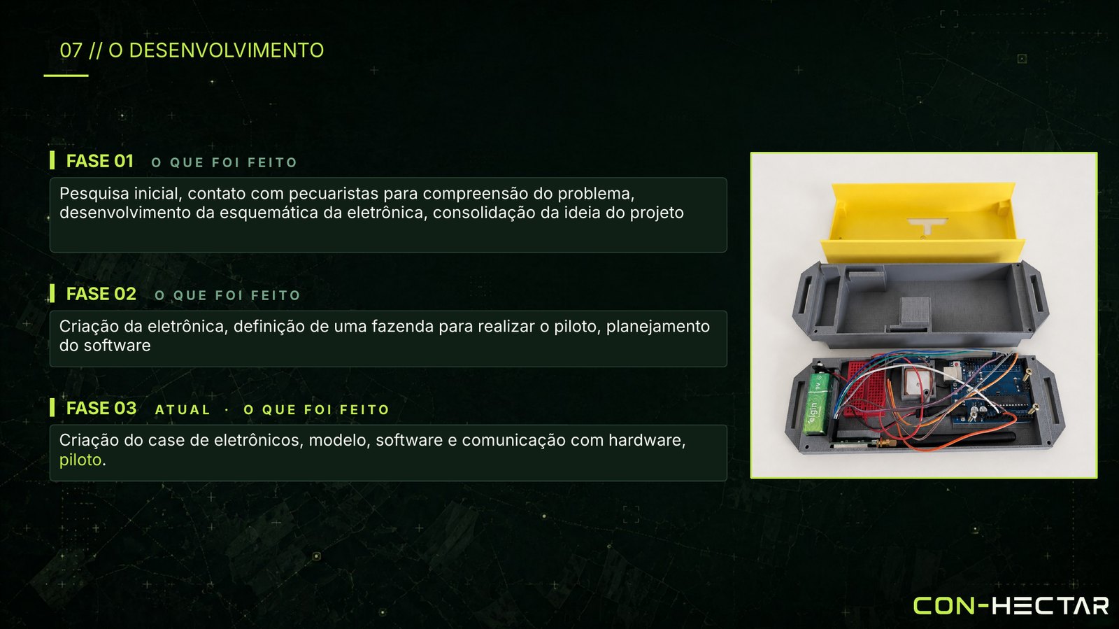
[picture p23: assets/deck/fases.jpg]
Fases do desenvolvimento


### Onde estamos

| Fase | | Status |
|:-:|---|:-:|
| **01** | Pesquisa com pecuaristas, esquemático da eletrônica, consolidação da ideia | ✅ |
| **02** | Eletrônica em bancada, fazenda-piloto definida, planejamento do software | ✅ |
| **03** | Case, modelos 3D, software e comunicação hardware ↔ nuvem; piloto | 🟢 em andamento |

### Próximos passos imediatos

- [ ] Estabilizar o link do gateway em campo (o último teste, sem Starlink, foi instável)
- [ ] Cyberdeck: gateway com sistema operacional e tela próprios, para monitoramento local sem rede
- [ ] Melhorar a geração automática de piquetes em períodos de seca e com poucas imagens limpas
- [ ] Coleira em PCB própria
- [ ] Piloto com +1 coleira ativa

### Horizonte do produto

| Fase | Foco | Entregas |
|---|---|---|
| **Confiança** | O cliente confia no dado | Ingestão robusta, mapa vivo, mapa de cobertura de rádio, desambiguação de silêncio, alertas críticos, app offline-first e alertas por WhatsApp |
| **Decisão** | As recomendações são seguidas | Pipeline de satélite completo, motor de rotação com dias de pasto restantes, curva de esgotamento, relatório mensal automático |
| **Alavancagem** | O dado vira ativo | Projeção de vazio forrageiro e simulador de cenários, módulo reprodutivo, modelos aprendidos por fazenda, integrações (PNIB, balança, GTA, CAR) e visão multi-fazenda para consultores |

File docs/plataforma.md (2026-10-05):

<picture><source media="(prefers-color-scheme: dark)" srcset="../assets/brand/logo-wordmark-tight-duotone.svg">Con-Hectar</picture>

# Plataforma

[← Voltar ao README](../README.md)

Painel Con-Hectar

Três superfícies, um único sistema de design:

| Superfície | Para quem | Stack |
|---|---|---|
| **Painel web** | Gerente e proprietário, no escritório ou na sede | Next.js 16 (App Router) · React 19 · TypeScript · Tailwind 4 · MapLibre GL |
| **App de campo** | Peão e capataz, no pasto, no sol, com sinal ruim | Expo · React Native · Expo Router (iOS, Android e Web) |
| **Landing page** | Pecuarista conhecendo o produto | Next.js · Three.js (visualizador 3D do hardware) |

---

## Os três modos de uso

O painel não é uma tela única: ele precisa servir bem a três trabalhos diferentes.

1. **Detecção rápida de anomalia** — tem algum animal fora da cerca, doente ou sem sinal *agora*?
2. **Análise histórica** — como o rebanho e as pastagens se comportaram ao longo do tempo, para decidir e reportar.
3. **Configuração** — desenhar cercas, cadastrar animais e coleiras, ajustar limiares.

O critério de sucesso é um só: **o gerente confiar no painel o bastante para agir sem ir conferir no campo.**

---

## Módulos

### Visão geral
"O que fazer hoje" — uma lista curta de recomendações priorizadas (tirar o lote do piquete X, uma coleira muda em área de boa cobertura, animais fora da cerca), ao lado do mapa e do resumo do rebanho. Cada fato aparece em **uma** superfície só — o painel foi deliberadamente enxugado para eliminar redundância.

### Mapa
Cada animal em tempo real sobre imagem de satélite, com trajetos, cercas, piquetes, gateways e pontos de recurso (água, cocho). Gateways e cochos são posicionados com um toque no mapa. Fixos de baixa qualidade aparecem, mas são marcados e nunca entram nos cálculos.

### Pastagens
O coração operacional:
- Piquetes desenhados no mapa, com **NDVI** sincronizado automaticamente do Sentinel-2
- Estado em semáforo: **ocupado · pronto · em descanso · descanso insuficiente**
- **Faixa de plano**: a sequência de rotação como cartões, com datas de entrada projetadas (sempre marcadas com `~`) e uma única ação — *Registrar mudança*
- Setas de fluxo no mapa: a mudança recomendada agora é sólida; a sequência projetada depois dela é tracejada — "faça isto" e "depois, provavelmente isto" nunca se confundem
- **Divisão automática** de uma pastagem em piquetes, com pré-visualização antes de confirmar
- Curva de esgotamento do piquete ao longo do ciclo de ocupação

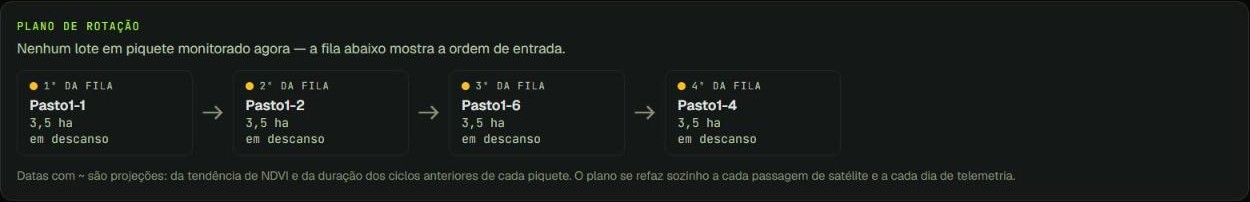
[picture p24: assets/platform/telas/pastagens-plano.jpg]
Plano de rotação


Mapa da rotação

### Cercas
Cercas virtuais com regras de entrada/saída e períodos de vigência. A detecção usa distância assinada até o polígono com **histerese** (dentro → aproximando → fora), para que um animal andando na linha da cerca não gere uma sequência de alertas piscando. As regras foram modeladas para que seja **impossível declarar uma combinação incoerente**.

> A coleira **detecta e avisa**; ela não contém o animal. Não há atuador no hardware, e o produto não promete o contrário.

Cercas virtuais

### Rebanho
Animais e lotes, com o vínculo animal ↔ coleira registrado ao longo do tempo.

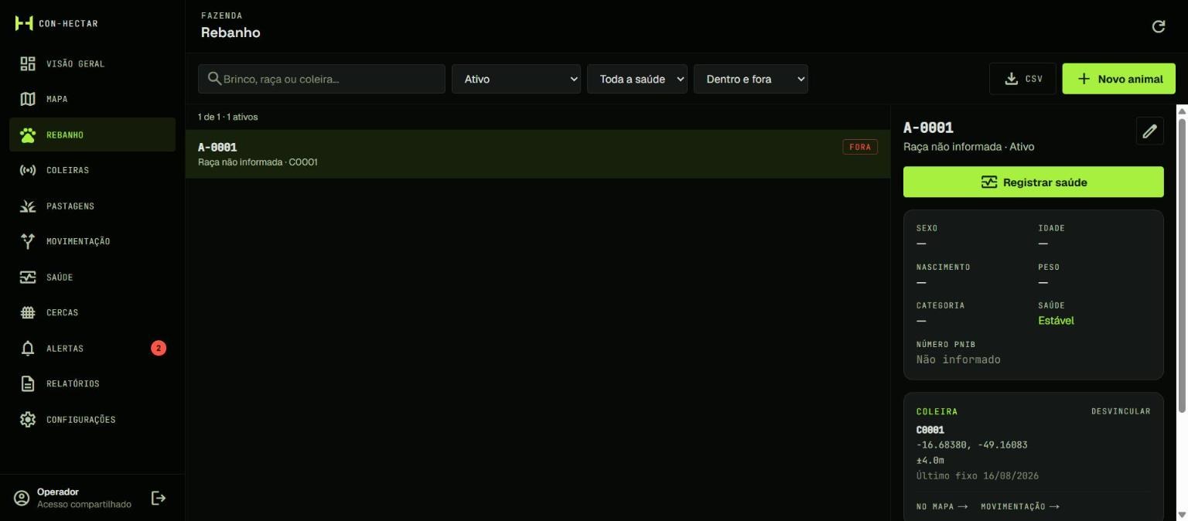
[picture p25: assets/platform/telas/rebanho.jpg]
Rebanho


### Coleiras
Estado de cada dispositivo, último fixo, qualidade do enlace de rádio e o **diagnóstico de silêncio** (ver [`inteligencia.md`](inteligencia.md#silêncio)).

Coleiras e diagnóstico de silêncio

### Movimentação
Distância diária filtrada, área de uso, sinuosidade e **orçamento de atividade** (parado · pastejo · deslocamento · trânsito) por animal e por lote, sempre comparados contra o próprio lote no mesmo dia.

Movimentação

### Saúde
Eventos sanitários registrados manualmente e anomalias comportamentais detectadas automaticamente, cada uma com a evidência que a produziu.

### Alertas
Central única, com severidade, frase curta "para ler no celular sob o sol", os números por trás da decisão e uma ação sugerida. **Todo alerta termina em uma ação — ou é ruído.**

### Relatórios e Configurações
Indicadores históricos para decisão e prestação de contas; parâmetros da fazenda, intervalo de amostragem e limiares.

---

## App de campo

App multiplataforma em Expo com mapa da fazenda (MapLibre nativo e web), rebanho, cercas e ajustes. O desenho de cercas funciona com o dedo, no próprio pasto. A mesma base de dados e o mesmo vocabulário visual do painel.

---

## Sistema de design — "The Ops Console"

O painel é um instrumento de controle de missão para gado no campo: feito para ser **escaneado**, não admirado.

| Token | Valor | Uso |
|---|---|---|
|  Console Black | `#060906` | Fundo |
|  Signal Lime | `#a8f040` | O único acento: ação primária, estado ativo, "está tudo certo" |
|  Signal Amber | `#fbbf24` | Atenção, não urgente |
|  Breach Red | `#ff5449` | Exclusivo para alerta crítico — nunca decorativo |

**Tipografia:** Space Grotesk (títulos) · Geist (texto e dados) · JetBrains Mono em caixa alta (tudo que se comporta como telemetria).

**Regras que guiam cada tela**
- **Três faixas de status, e só três.** Um estado novo ganha rótulo e ícone, nunca uma cor nova.
- **Profundidade só por tons**, sem sombra nem desfoque no painel.
- **Contraste verificável:** nenhum texto com opacidade — todo tom de texto passa 4,5:1 em todas as superfícies (WCAG 2.1 AA).
- **Movimento significa algo:** animação só para mudança de estado ao vivo.
- **Duas intensidades, um sistema:** a landing page "performa" (brilho, scanlines, cerca se desenhando); o console "trabalha".
- **Paridade campo e mesa:** toda tela funciona num monitor e num celular ao ar livre.
- **Honestidade:** todo número da landing page rastreia até uma medição ou um modelo; o que é calculado diz que é calculado, e a página tem uma seção sobre **o que o equipamento não faz**.

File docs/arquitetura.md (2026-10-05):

<picture><source media="(prefers-color-scheme: dark)" srcset="../assets/brand/logo-wordmark-tight-duotone.svg">Con-Hectar</picture>

# Arquitetura

[← Voltar ao README](../README.md)

A Con-Hectar é um sistema ponta a ponta: do receptor GNSS no pescoço do animal até a recomendação de manejo na tela do gerente. Cada elo foi construído e colocado de pé separadamente — porque uma falha em qualquer um deles parece idêntica do outro lado: **nenhum ponto no mapa**.

---

## 1. A cadeia

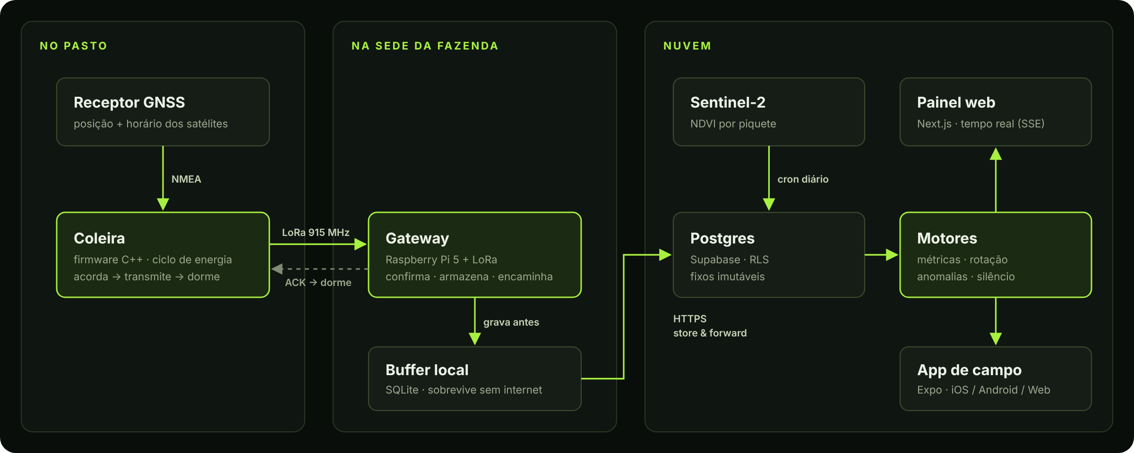
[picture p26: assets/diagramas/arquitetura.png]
Cadeia Con-Hectar: coleira → LoRa → gateway → nuvem → painel e app


| Elo | Tecnologia | Responsabilidade |
|---|---|---|
| Coleira | Microcontrolador + GNSS + LoRa · C++ | Obter um fixo, entregá-lo com confirmação, dormir |
| Rádio | LoRa sub-GHz, faixa ISM homologável pela ANATEL | Longo alcance, baixíssimo consumo, sem depender de operadora |
| Gateway | Raspberry Pi 5 · Python · `systemd` | Confirmar, persistir localmente, encaminhar, podar |
| Banco | Supabase (Postgres + Realtime + RLS) | Fonte da verdade; fixos imutáveis |
| Satélite | Copernicus Sentinel-2 via API estatística | NDVI por piquete, sem intervenção humana |
| Web | Next.js 16 · React 19 · MapLibre GL · Three.js | Painel de gestão e landing page |
| Mobile | Expo · React Native | App de campo para iOS, Android e Web |
| Deploy | Vercel (web + cron) | Deploy contínuo a partir do branch principal |

---

## 2. Protocolo de rádio

Um protocolo textual, compacto e verificável — inspirado em NMEA — desenhado para ser depurável com um monitor serial e robusto o bastante para várias coleiras dividindo o mesmo canal.

```
$P,<coleira>,<seq>,<timestamp>,<lat>,<lng>,<vel>,<rumo>,<sats>,<hdop>*XX   fixo
$S,<coleira>,<seq>,<sats>,<diag>*XX                                       sem fixo neste ciclo
$A,<coleira>,<seq>*XX                                                      gateway → coleira
```

`XX` é um checksum XOR. Três decisões fazem a diferença:

- **O timestamp vem dos satélites, não do gateway.** Um fixo que ficou horas no buffer ainda registra quando foi realmente tomado.
- **`$S` existe de propósito.** Uma coleira que não enxerga o céu ainda completa o ciclo e dorme — e o enlace de rádio continua testável dentro de casa.
- **Compartilhar o ar.** Cada coleira constrói exatamente o ACK que espera (endereço + sequência), então o ACK de outra coleira — ou um ACK atrasado do ciclo anterior — nunca é aceito. Atrasos antes da transmissão e entre tentativas são aleatórios e semeados por dispositivo, para que duas coleiras que acordam juntas se afastem em vez de colidir a cada nova tentativa.

```mermaid
sequenceDiagram
  participant C as Coleira
  participant G as Gateway
  participant N as Nuvem
  C->>C: acorda · busca fixo GNSS
  C->>G: $P,C0001,26,…*2B
  G->>G: grava no SQLite
  G-->>C: $A,C0001,26*07
  C->>C: dorme
  G->>N: upload (quando houver internet)
```

---

## 3. A decisão mais importante: o ACK não espera a nuvem

Uma coleira mantém o rádio ligado até ouvir a confirmação. Se o ACK dependesse do upload, **toda coleira ficaria acordada durante uma queda de internet** — exatamente quando a bateria mais importa. Por isso o gateway confirma no instante em que o fixo está no **próprio disco**. A partir daí a coleira não deve mais nada e pode dormir; o acúmulo é drenado depois.

O gateway também poda o buffer local com um teto de retenção, para que meses de operação offline não esgotem o cartão SD.

---

## 4. Modelo de dados

O modelo foi desenhado em torno de uma regra: **os dados brutos são imutáveis; tudo o que é calculado pode ser destruído e reconstruído do zero.** Os algoritmos vão mudar dezenas de vezes no primeiro ano — o histórico por animal, não.

```mermaid
erDiagram
  FAZENDA ||--o{ PIQUETE : contém
  FAZENDA ||--o{ PONTO_DE_RECURSO : contém
  FAZENDA ||--o{ LOTE : contém
  LOTE ||--o{ ANIMAL : agrupa
  ANIMAL ||--o{ VINCULO_COLEIRA : "usa ao longo do tempo"
  COLEIRA ||--o{ VINCULO_COLEIRA : ""
  COLEIRA ||--o{ FIXO : reporta
  PIQUETE ||--o{ OBSERVACAO_NDVI : "observado por satélite"
  PIQUETE }o--o{ PONTO_DE_RECURSO : "servido por"
  FIXO ||--o{ ANIMAL_DIA : "deriva"
  PIQUETE ||--o{ PIQUETE_DIA : "deriva"
```

- **Vínculo animal ↔ coleira é temporal**, com início e fim — a troca de coleira entre animais é a operação mais comum e a mais mal modelada em produtos do setor.
- **Área útil ≠ área do polígono.** Açude, mata e estrada são descontados; o erro aqui se propagaria para todo o balanço forrageiro.
- **Pontos de recurso** (água, cocho, sombra, porteira) têm relação N:N com piquetes — um bebedouro pode servir dois.
- Cada métrica derivada carrega a **versão do algoritmo** que a calculou, para que "o número mudou sozinho" tenha resposta.

---

## 5. Tempo real

Posições chegam ao painel por um stream **Server-Sent Events** autenticado pela sessão do usuário. O cliente reconecta sozinho, enquadra o mapa automaticamente nas coleiras ativas e diferencia visualmente fixos de baixa qualidade (que aparecem no mapa, mas não entram em nenhum cálculo).

---

## 6. Segurança

| Camada | Medida |
|---|---|
| Banco | Row Level Security em todas as tabelas; funções internas fora do schema público exposto pela API REST |
| Stream ao vivo | Exige sessão válida — `401` sem cookie, `200` com cookie (verificado) |
| Jobs agendados | Rotas de cron protegidas por segredo compartilhado |
| Segredos | Somente em variáveis de ambiente; nada versionado |

---

## 7. Princípios de engenharia

1. **Cada salto é testado isoladamente.** Coleira, rádio, gateway, banco e mapa têm cada um sua própria verificação.
2. **Medido ≠ calculado.** Toda documentação marca qual é qual.
3. **Nenhum número inventado.** A coleira não mede bateria — então o painel não mostra bateria. Preferimos remover uma tela a exibir um dado que teríamos de adivinhar.
4. **Silêncio nunca é ambíguo.** "Animal parado" e "coleira sem cobertura" são estados diferentes, com mensagens e ações diferentes.
5. **Offline-first.** Só ~34 % da área agrícola brasileira tem cobertura 4G/5G. O sistema assume que a internet vai cair.

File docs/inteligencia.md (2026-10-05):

<picture><source media="(prefers-color-scheme: dark)" srcset="../assets/brand/logo-wordmark-tight-duotone.svg">Con-Hectar</picture>

# A inteligência

[← Voltar ao README](../README.md)

> Todo produto de telemetria bovina que fracassou no Brasil fracassou pelo mesmo motivo: entregou **posição** quando o pecuarista precisava de **decisão**. Um mapa com bolinhas vai do "uau" ao "e daí?" em cerca de três semanas.

A Con-Hectar transforma uma série de coordenadas com carimbo de tempo — e nada mais — em decisões de manejo. Este documento descreve **o que** cada camada faz e **por que** foi desenhada assim. Limiares, fórmulas e parâmetros calibrados ficam no código proprietário.

```mermaid
flowchart TB
  F[("Fixos brutos<br/>imutáveis")] --> L1
  L1["<b>1 · Comportamento</b><br/>métricas por animal-dia"] --> L2
  L2["<b>2 · Piquete</b><br/>ciclo de ocupação"] --> L4
  S2[("Sentinel-2")] --> L3
  L3["<b>3 · Satélite</b><br/>NDVI com limiares aprendidos"] --> L4
  L4["<b>4 · Rotação</b><br/>sair · para onde · quanto resta"] --> OUT
  L1 --> L5["<b>5 · Alertas</b><br/>anomalias · silêncio"] --> OUT
  OUT(["O que fazer hoje"])
```

---

## 1 · Comportamento — tudo que se extrai de posição e tempo

A coleira reporta latitude, longitude e horário. Não mede temperatura, ruminação, peso nem aceleração — e o software nunca finge que mede. Ainda assim, isso basta para **cerca de vinte métricas úteis por animal-dia**: distância percorrida, deslocamento líquido, sinuosidade, raio de giro, área de uso (polígono convexo mínimo), tempo parado, centroide diário e o **orçamento de atividade** — a fração do dia em *repouso*, *pastejo*, *deslocamento* e *trânsito*.

Três regras governam cada número:

| Regra | Por quê |
|---|---|
| **O intervalo de amostragem é sagrado** | O mesmo animal "anda menos" se amostrado a cada 60 min do que a cada 15. Cada dia carrega o intervalo em que foi calculado, e a plataforma **se recusa** a comparar dias com intervalos diferentes. |
| **Erro de GNSS infla distância** | Fixos sucessivos de um animal deitado produzem "caminhada fantasma" — cerca de +15 % na distância diária. Segmentos abaixo de um limiar de ruído são descartados antes da soma. |
| **Isto não é velocidade** | Com fixos espaçados, mede-se taxa de deslocamento líquido, não comprimento de caminho. Um animal pastejando em círculo registra quase zero — e isso é um sinal legítimo, exatamente o que separa pastejo de deslocamento. A interface nunca o chama de "velocidade" sem qualificar. |

Cada dia também registra sua **cobertura** (fixos recebidos ÷ esperados) e a versão do algoritmo. Um dia com cobertura baixa não é tratado como confiável.

---

## 2 · Piquete — o ciclo de ocupação

As métricas individuais são agregadas por lote e por ciclo de ocupação de cada piquete. O produto central desta camada é a **curva de esgotamento**: conforme a forragem acaba, o tempo de pastejo e a distância diária sobem de forma monotônica. Na literatura com bovinos de corte sob GNSS, o tempo de pastejo subiu de 31 % para 69 % das horas de luz ao longo de um único ciclo (r² = 0,71), e a distância diária cresceu linearmente (r² = 0,88).

**O rebanho avisa que o piquete acabou antes de o satélite conseguir ver.**

---

## 3 · Satélite — forragem sem calibração manual

Um job agendado busca **NDVI zonal do Sentinel-2** para cada piquete com cerca desenhada e grava cada observação com sua fração de cobertura limpa (sem nuvem).

A literatura é clara sobre as duas faces do NDVI: ele **ranqueia e acompanha** um piquete contra ele mesmo muito bem (r² ≈ 0,91 para mudança relativa), e **estima massa seca absoluta** mal sem calibração local (r² ≈ 0,37). A Con-Hectar abre mão do segundo para manter o primeiro honesto:

- **Nenhum kg MS/ha é exibido.** O produto não afirma o que não consegue medir.
- **Os limiares de entrada e saída são aprendidos do histórico do próprio piquete**, não de uma tabela de espécies nem de uma altura digitada. Não há nada para o operador escolher.
- Um piquete novo usa um padrão provisório da literatura — marcado como provisório em todo lugar — até acumular histórico suficiente.
- Passagens antigas ou com pouca cobertura limpa perdem peso na confiança "atual".
- "Dias de pasto restantes" é uma projeção da tendência de queda, exibida **apenas** quando a tendência a sustenta.

---

## 4 · Rotação — o coração do produto

Tudo o mais existe para alimentar esta camada. Ela responde às três perguntas do pecuarista.

### Quando sair? — o voto de duas fontes

```mermaid
flowchart LR
  SAT["🛰️ Satélite<br/>NDVI vs. limiar aprendido"] --> V{Decisão de saída}
  BEH["🐂 Comportamento<br/>tendência do lote no ciclo"] --> V
  V -->|concordam| R1[Recomendação clara]
  V -->|discordam| R2["Comportamento vence<br/>+ discordância exibida"]
  V -->|sem dados| R3[Diz que não sabe]
```

Cada fonte vota *sair*, *seguir* ou *sem dados*. Quando discordam, **o comportamento vence** — o animal está dentro do piquete, e a última passagem limpa do satélite pode ter três semanas. A interface mostra a discordância em vez de escondê-la.

### Para onde? — a fila de rotação

Cada piquete tem um estado (**ocupado · pronto · em descanso · descanso insuficiente**) e um tempo de descanso que pode vir de três fontes, sempre identificadas: definido manualmente, **aprendido** dos ciclos anteriores do próprio piquete, ou padrão. A fila ordena os candidatos pela recuperação observada no satélite e pelo descanso cumprido, e projeta datas de entrada — sempre com `~`, porque são estimativas.

### Carga do lote

A carga é expressa em **Unidade Animal** (a língua que o pecuarista fala) por hectare **pastejável** — a área útil, não o polígono — o que a torna comparável entre piquetes e entre fazendas.

### Divisão automática de pastagens

Uma pastagem desenhada pode ser dividida em N piquetes cortados perpendicularmente ao seu eixo maior (como um cerqueiro passaria o fio), com **área pastejável equivalente** e balanceamento pelo NDVI. O número sugerido de piquetes segue a fórmula clássica do pastejo rotacionado a partir dos dias de descanso e de ocupação. Geometria pura sobre o que a fazenda já desenhou: nenhum dado é inventado, e cada faixa vira uma cerca real que o resto da plataforma trata como qualquer outra.

---

## 5 · Alertas

### Anomalias

| Alerta | Severidade | O que indica |
|---|:-:|---|
| Falha de aguada | 🔴 crítica | Comportamento anômalo do lote inteiro ligado ao ponto de água — infraestrutura, não doença |
| Animal caído | 🔴 crítica | Sem deslocamento por tempo prolongado, **com a coleira ainda transmitindo** |
| Possível doença | 🟠 alta | Atividade persistentemente muito abaixo do lote |
| Isolamento | 🟠 alta | Animal longe do centro do lote, em relação à dispersão do próprio lote |
| Coesão do rebanho | 🟠 alta | O lote se dispersando de forma atípica |
| Candidato a cio | 🟡 média | Pico de atividade contra a linha de base do próprio animal |

Quatro regras não são opcionais:

1. **Linha de base robusta** (mediana e MAD, nunca média e desvio-padrão). As distribuições têm caudas pesadas, e um único dia de manejo destrói uma média.
2. **Toda pontuação é normalizada contra o lote no mesmo dia** antes de virar alerta. Isso elimina chuva, calor, troca de piquete e manejo como classe inteira de falso positivo.
3. **Persistência, não uma janela só.** Um alerta que pisca é um alerta ignorado.
4. **Dez animais com a mesma anomalia no mesmo piquete são um alerta de lote**, não dez alertas individuais — e esse agrupamento já é o diagnóstico: aponta para água, cerca ou porteira.

Cada alerta carrega uma frase curta, **os números que o produziram** (ninguém precisa confiar numa caixa-preta) e **o que fazer a seguir**.

### Silêncio

Quando uma coleira para de falar, há causas muito diferentes — e tratá-las como um alerta único destrói a credibilidade do produto, porque a maioria é banal e uma é emergência.

| Classificação | Evidência usada |
|---|---|
| **Reportando** | Uplinks chegando normalmente |
| **Nunca reportou** | Dispositivo cadastrado sem nenhum fixo |
| **Provável sombra de rádio** | Último enlace já no limite (RSSI/SNR) e/ou vizinhos próximos também em silêncio |
| **Falha de dispositivo** | Silêncio em área de boa cobertura, com vizinhos reportando normalmente |
| **Silêncio sem explicação** | Nenhuma das anteriores — investigar |

Cada veredito tem um grau de confiança, uma mensagem pronta para encaminhar por WhatsApp e a evidência por trás. A plataforma também constrói um **mapa de cobertura de rádio** e a **taxa de entrega** por coleira — as sombras de rádio explicam a maior parte dos "sumiços" e são o principal argumento para posicionar gateways adicionais.

**Bateria fica de fora de propósito:** a coleira não reporta carga, então um veredito de bateria seria um palpite fantasiado de evidência.

---

## O que não prometemos

Sem trocar o hardware, a Con-Hectar **não** promete ruminação, temperatura corporal, peso, cerca virtual com contenção por estímulo, ou estimativa absoluta de massa de forragem sem calibração. Um sistema que só lista suas forças não pode ser verificado.

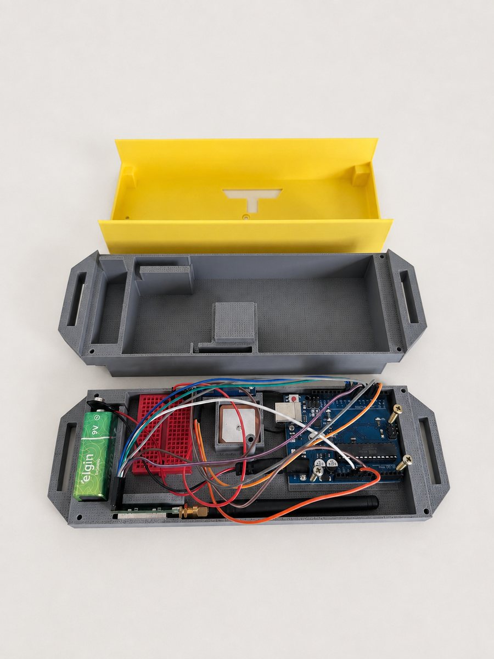
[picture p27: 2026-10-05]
assets/hardware/coleira-aberta.jpg

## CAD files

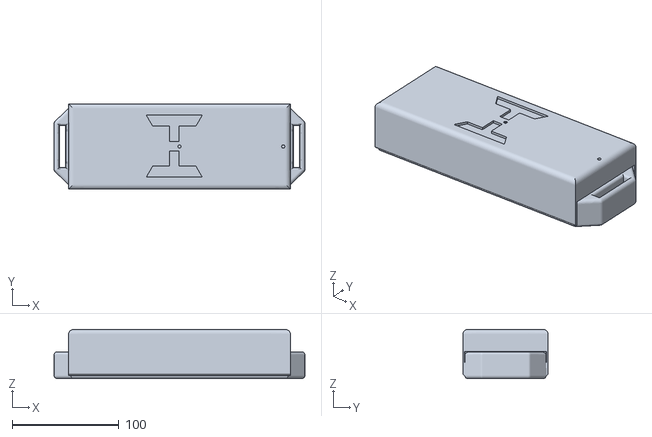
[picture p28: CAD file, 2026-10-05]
models/coleira.stl
235.0 x 79.9 x 46.0

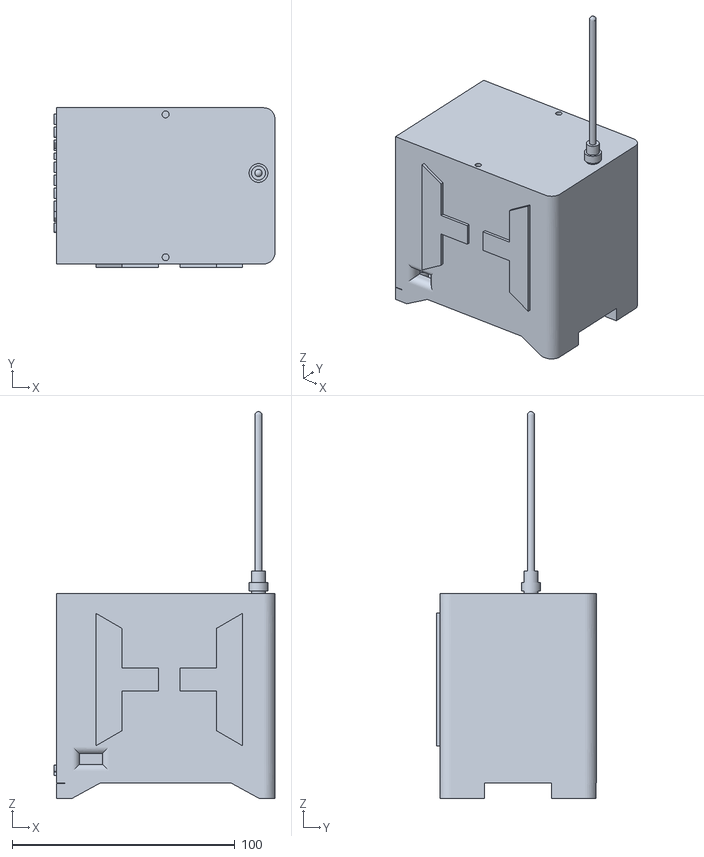
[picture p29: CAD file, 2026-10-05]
models/gateway.stl
99.1 x 71.6 x 173.6

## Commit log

2026-10-05 Documentação técnica e de negócio
2026-10-05 Imagens do pitch
2026-10-05 Telas do app de campo, dashboard e tablet
2026-10-05 Modelos 3D da coleira e do gateway (STL)
    [coleira.stl, gateway.stl]
2026-10-05 Docs: grades alinhadas, logo para tema claro e escuro
2026-10-05 README: números de mercado em linha única
2026-10-05 Diagrama de arquitetura
2026-10-05 Docs: diagrama de arquitetura e foto em paisagem
2026-10-05 Coleira: modelo 3D com a tampa para cima
    [coleira.stl]
2026-10-05 Docs: sem telas de conceito; gateway instável sem Starlink e cyberdeck no roadmap
2026-10-05 README: sem conceito de app; gateway instável sem Starlink e cyberdeck
2026-10-05 Render 3D da coleira com a tampa para cima
